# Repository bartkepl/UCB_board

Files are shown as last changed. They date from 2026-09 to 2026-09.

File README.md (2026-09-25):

# UCB (Universal Control Board)
Control board for testing concepts with SCPI, UART, USB, RS485 and ETHERNET in 3U eurocard format

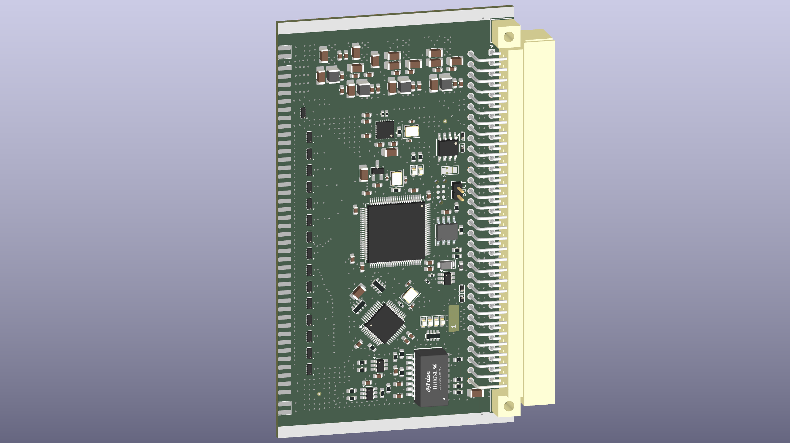
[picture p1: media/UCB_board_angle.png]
Universal Control board


| Top | Bottom |
|---|---|
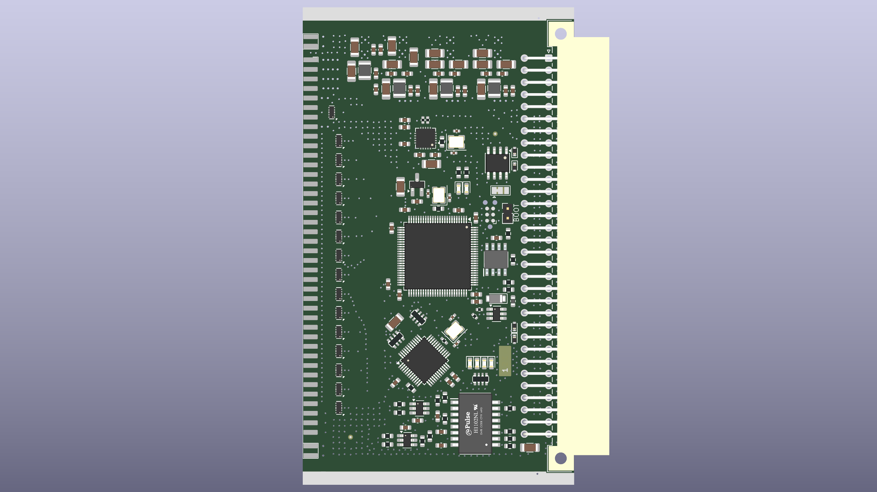
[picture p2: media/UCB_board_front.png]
Top
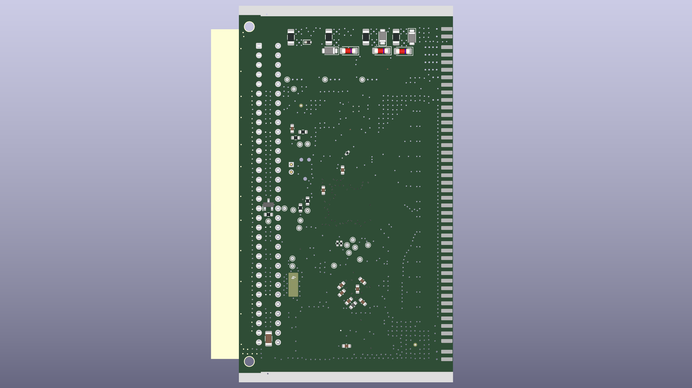
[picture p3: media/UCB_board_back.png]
Bottom
|  |  |

---
## Status: ready for prototype order

- Schematic and PCB layout done (4-layer, 56.8 × 100 mm), production files generated.
- Design review completed; DRC/ERC clean (remaining items reviewed and excluded as by-design).
- W5500 clock is sourced from the MCU (MCO1) by default — R80 fitted, R23 (Si5351C CLK0) DNP.
- Firmware: STM32CubeMX skeleton only.

Production outputs: [schematic PDF](prod/sch/UCB_board.pdf) · [PCB PDF](prod/pcb/UCB_board.pdf) · [interactive BOM](prod/ibom/UCB_board_ibom.html) · [gerbers](prod/UCB_board.zip)

---
## Features:
- ARM Cortex-M33 Processor in LQFP100 (STM32H563VIT6) 
- USB 2.0
- 10/100 Ethernet (based on WIZnet W5500)
- UART
- Half-duplex RS485 
- 3U eurocard IEEE 1101.1-1998 format (160x100 mm) — this 56.8 × 100 mm backend board is combined with a 100 × 100 mm front module (e.g. SSM_board)
----

## License and Contribution

[MIT License](/LICENSE)

Open to contributions in both software and hardware!

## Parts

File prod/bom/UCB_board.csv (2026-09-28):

Oznaczenie | Wartość | Footprint | Opis | Liczba
C1,C2,C11,C12,C13,C14,C15,C16,C17,C23,C24,C26,C28,C29,C32,C33,C35,C37,C38,C39,C41,C42,C45,C46,C49,C50,C52,C53,C54,C55,C58,C68,C69,C70,C71 | 100n | Capacitor_SMD:C_0603_1608Metric | Unpolarized capacitor | 35
C3,C5 | 1nF/2kV | Capacitor_SMD:C_1206_3216Metric | Unpolarized capacitor | 2
C4,C7,C10,C27 | 10n | Capacitor_SMD:C_0603_1608Metric | Unpolarized capacitor | 4
C6,C8 | 18p | Capacitor_SMD:C_0402_1005Metric_Pad0.74x0.62mm_HandSolder | Unpolarized capacitor | 2
C9,C56,C57 | 4.7u | Capacitor_SMD:C_0603_1608Metric | Unpolarized capacitor | 3
C18,C21,C22,C30,C31,C34,C36,C43,C47,C48,C51,C67 | 10u | Capacitor_SMD:C_1206_3216Metric | Unpolarized capacitor | 12
C73,C74 | 6.8n | Capacitor_SMD:C_0603_1608Metric | Unpolarized capacitor | 2
D1,D2,D4,D6,D13,D14 | Green | LED_SMD:LED_0603_1608Metric | Light emitting diode | 6
D3,D5,D10,D16,D17 | ESD5Z3.3T1G | Diode_SMD:D_SOD-523 | ESD Protection Diode, SOD-523 | 5
D7,D12 | SMF5.0CA | Diode_SMD:D_SMF | SMF5.0CA | 2
D8,D18 | TGL34-15CA | Diode_SMD:D_MiniMELF | TGL34-15CA | 2
D9,D19 | BZD27C12P-E3-08 | Diode_SMD:D_SMF |  | 2
D11 | TGL34-6.8CA | Diode_SMD:D_MiniMELF | TGL34-6.8CA | 1
D15 | CDSOT23-SM712 | SamacSys_Parts:SOT95P230X117-3N | TVS Diode Dual Bi-Dir 7/12V 30KV SOT23 Bourns CDSOT23-SM712 Dual Bi-Directional TVS Diode, 400W peak, 3-Pin SOT-23 | 1
D20,D21,D22,D23,D24,D25,D26,D27,D28,D29,D30,D31,D32,D33,D34,D35 | UT8413A | Package_DFN_QFN:Diodes_UDFN-10_1.0x2.5mm_P0.5mm | TRANSIENT VOLTAGE SUPPRESSOR (TVS) ARRAY | 16
F1,F2,F3,F4 | Polyfuse | Fuse:Fuse_1206_3216Metric_Pad1.42x1.75mm_HandSolder | Resettable fuse, polymeric positive temperature coefficient | 4
FB1,FB2 | 100 @ 100MHz | Inductor_SMD:L_0603_1608Metric | Inductor | 2
IC1 | SN65HVD75DR | SamacSys_Parts:SOIC127P600X175-8N | 3.3-V half-duplex RS-485 transceiver with IEC ESD, 20 Mbps | 1
L1,L2,L3,L4 | LQH32PN101MN0L | Inductor_SMD:L_1210_3225Metric | Inductor | 4
R1,R2 | 22 | Resistor_SMD:R_0402_1005Metric | Resistor | 2
R3,R21,R84,R85,R90,R91 | 10k | Resistor_SMD:R_0603_1608Metric | Resistor | 6
R4 | 15k | Resistor_SMD:R_0603_1608Metric | Resistor | 1
R5,R88,R89 | 10 | Resistor_SMD:R_0603_1608Metric | Pulse-Proof Thick-Film Resistor,Resistor | 3
R6,R7 | 75 | Resistor_SMD:R_0603_1608Metric | Resistor | 2
R8,R9 | 82 | Resistor_SMD:R_0603_1608Metric | Resistor | 2
R10,R11 | 49.9 | Resistor_SMD:R_0603_1608Metric | Resistor | 2
R12,R13 | 150 | Resistor_SMD:R_0603_1608Metric | Resistor | 2
R14,R15,R16,R17 | 33 | Resistor_SMD:R_0603_1608Metric | Resistor | 4
R18,R20 | 1M | Resistor_SMD:R_0402_1005Metric_Pad0.72x0.64mm_HandSolder,Resistor_SMD:R_0603_1608Metric | Resistor | 2
R19 | 12.4k | Resistor_SMD:R_0603_1608Metric | Resistor | 1
R80 | 0R | Resistor_SMD:R_0402_1005Metric | Resistor | 1
R86,R87 | 120 | Resistor_SMD:R_0603_1608Metric | Resistor | 2
RN1 | 4x470R | Resistor_SMD:R_Array_Convex_4x0603 | Resistor array | 1
RN2,RN3 | 4x10k | Resistor_SMD:R_Array_Convex_4x0603 | Resistor array | 2
T1 | H1102NL | SamacSys_Parts:SOIC127P940X597-16N | PULSE ELECTRONICS - H1102NL - TRANSFORMER, 1:1, 1PORT, 100BASE-TX, SMT | 1
U1 | W5500 | Package_QFP:LQFP-48_7x7mm_P0.5mm | 10/100Mb SPI Ethernet controller with TCP/IP stack, LQFP-48 | 1
U2 | LM4040DBZ-3 | Package_TO_SOT_SMD:SOT-23_Handsoldering | 3.000V Precision Micropower Shunt Voltage Reference, SOT-23 | 1
U3,U4,U5 | USBLC6-2SC6 | Package_TO_SOT_SMD:SOT-23-6_Handsoldering | Very low capacitance ESD protection diode, 2 data-line, SOT-23-6 | 3
U6 | FM24C64B | Package_SO:SOIC-8_3.9x4.9mm_P1.27mm | 64Kb serial FRAM nonvolatile Memory, SOIC-8 | 1
U7 | STM32H563VIT6 | Package_QFP:LQFP-100_14x14mm_P0.5mm | STMicroelectronics Arm Cortex-M33 MCU, 2048KB flash, 640KB RAM, 250 MHz, 1.62-3.6V, 80 GPIO, LQFP100 | 1
Y2 | 3225-25M-SR | Crystal:Crystal_SMD_3225-4Pin_3.2x2.5mm | Four pin crystal, GND on pins 2 and 4 | 1

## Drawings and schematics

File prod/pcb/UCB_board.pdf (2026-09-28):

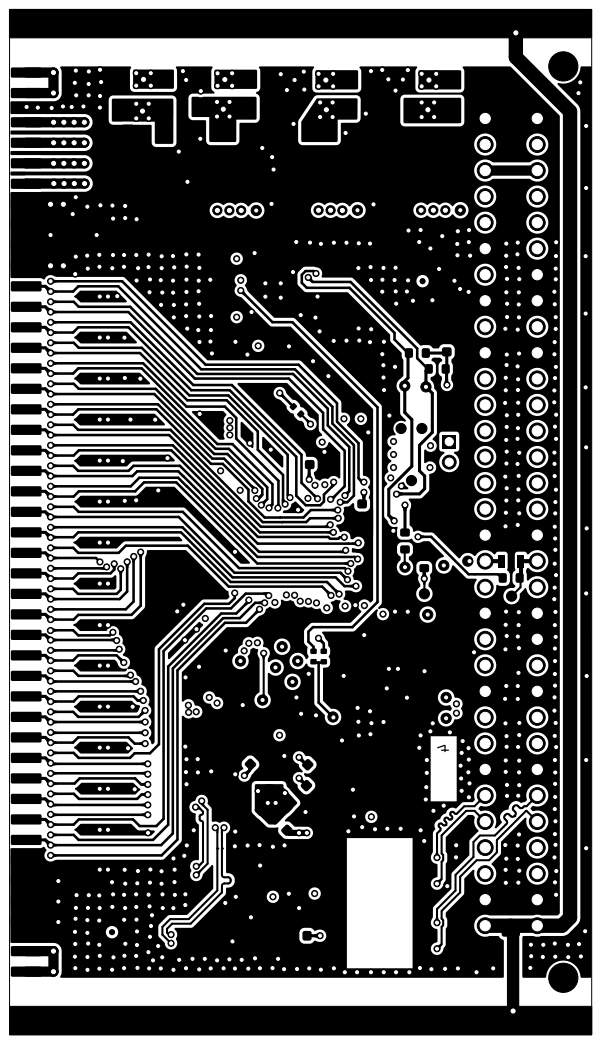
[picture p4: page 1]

Size: A4 | Rev: 0.3
KiCad E.D.A. 10.0.4 | Id: 1/6

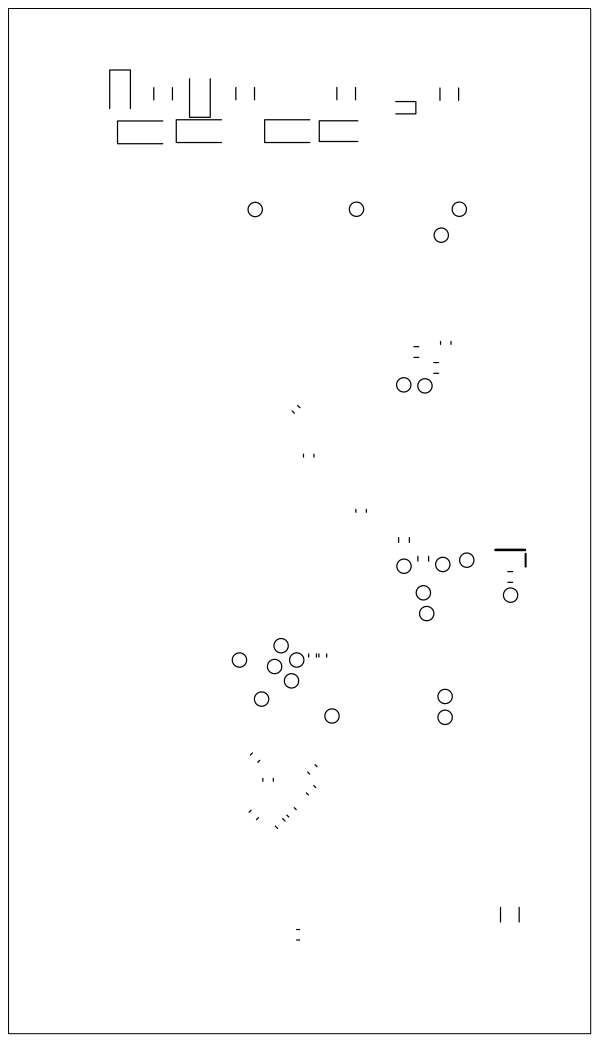
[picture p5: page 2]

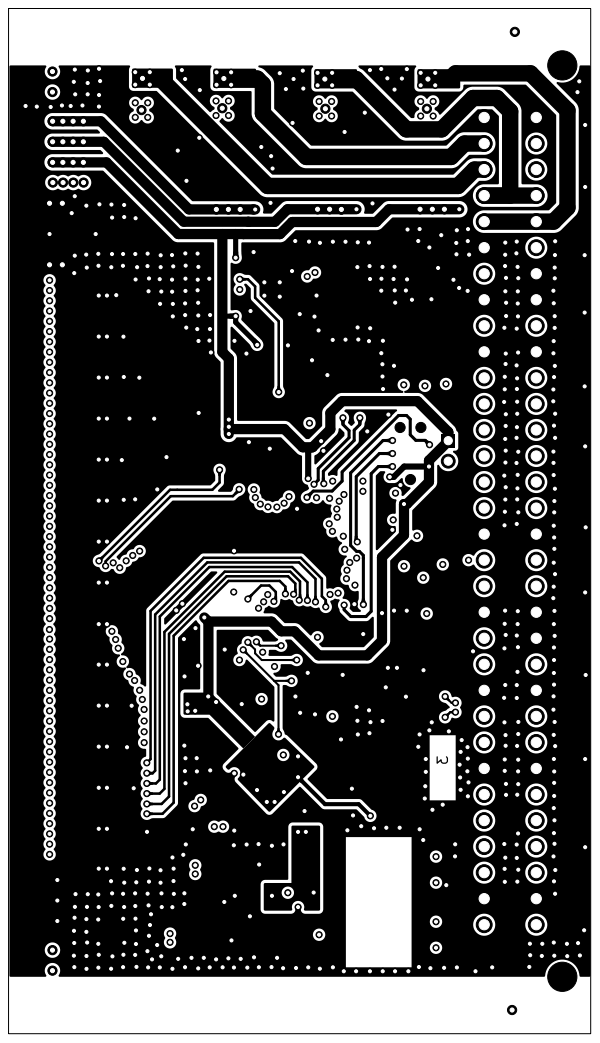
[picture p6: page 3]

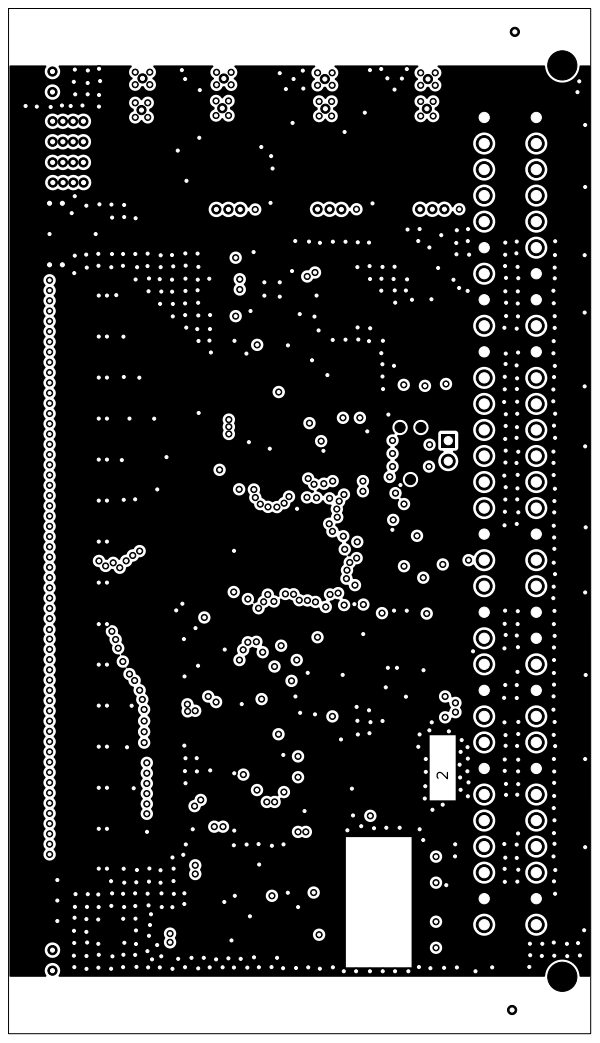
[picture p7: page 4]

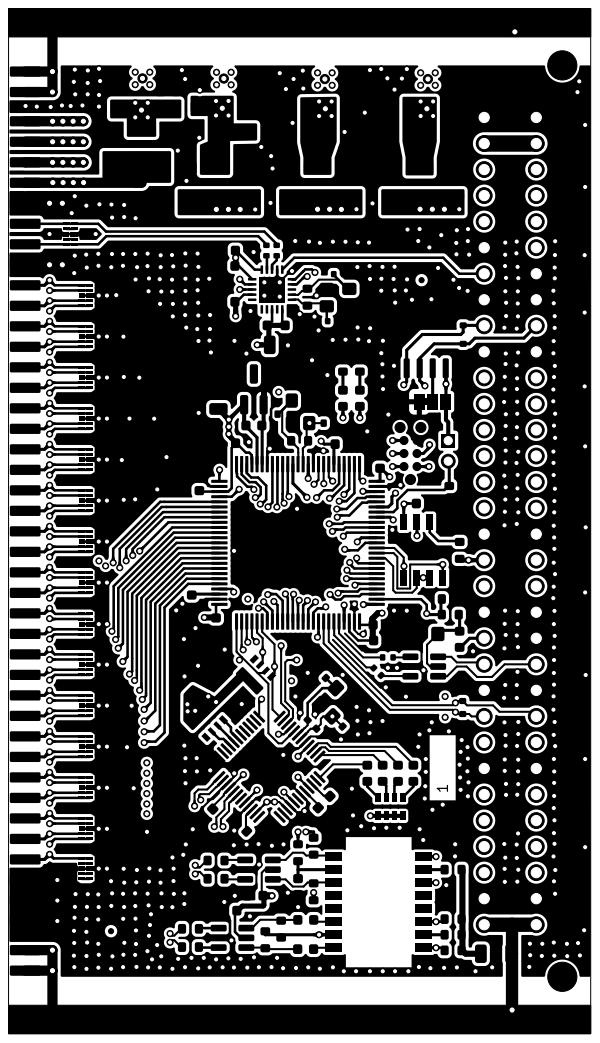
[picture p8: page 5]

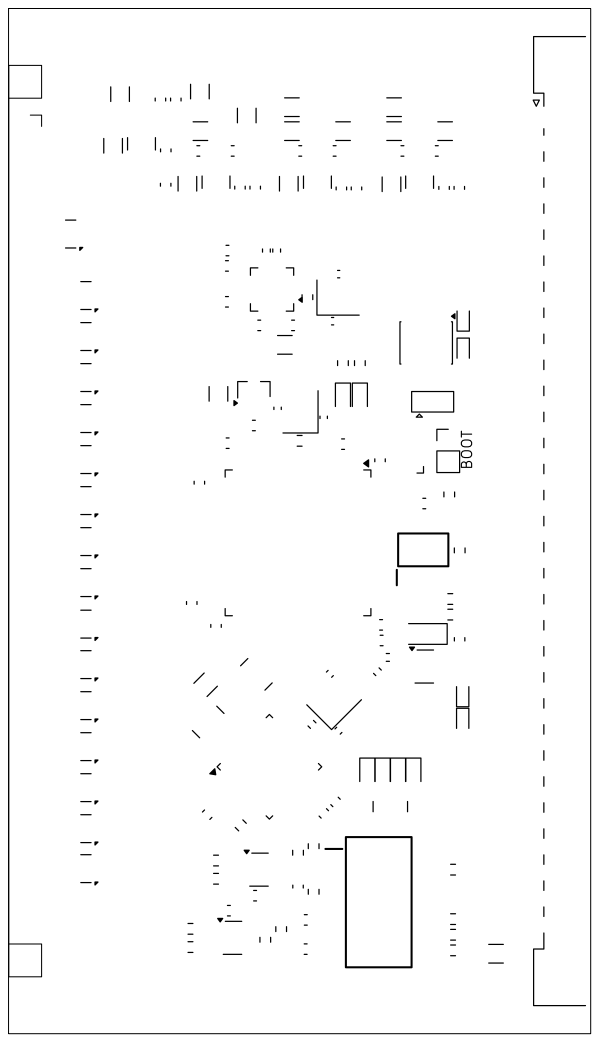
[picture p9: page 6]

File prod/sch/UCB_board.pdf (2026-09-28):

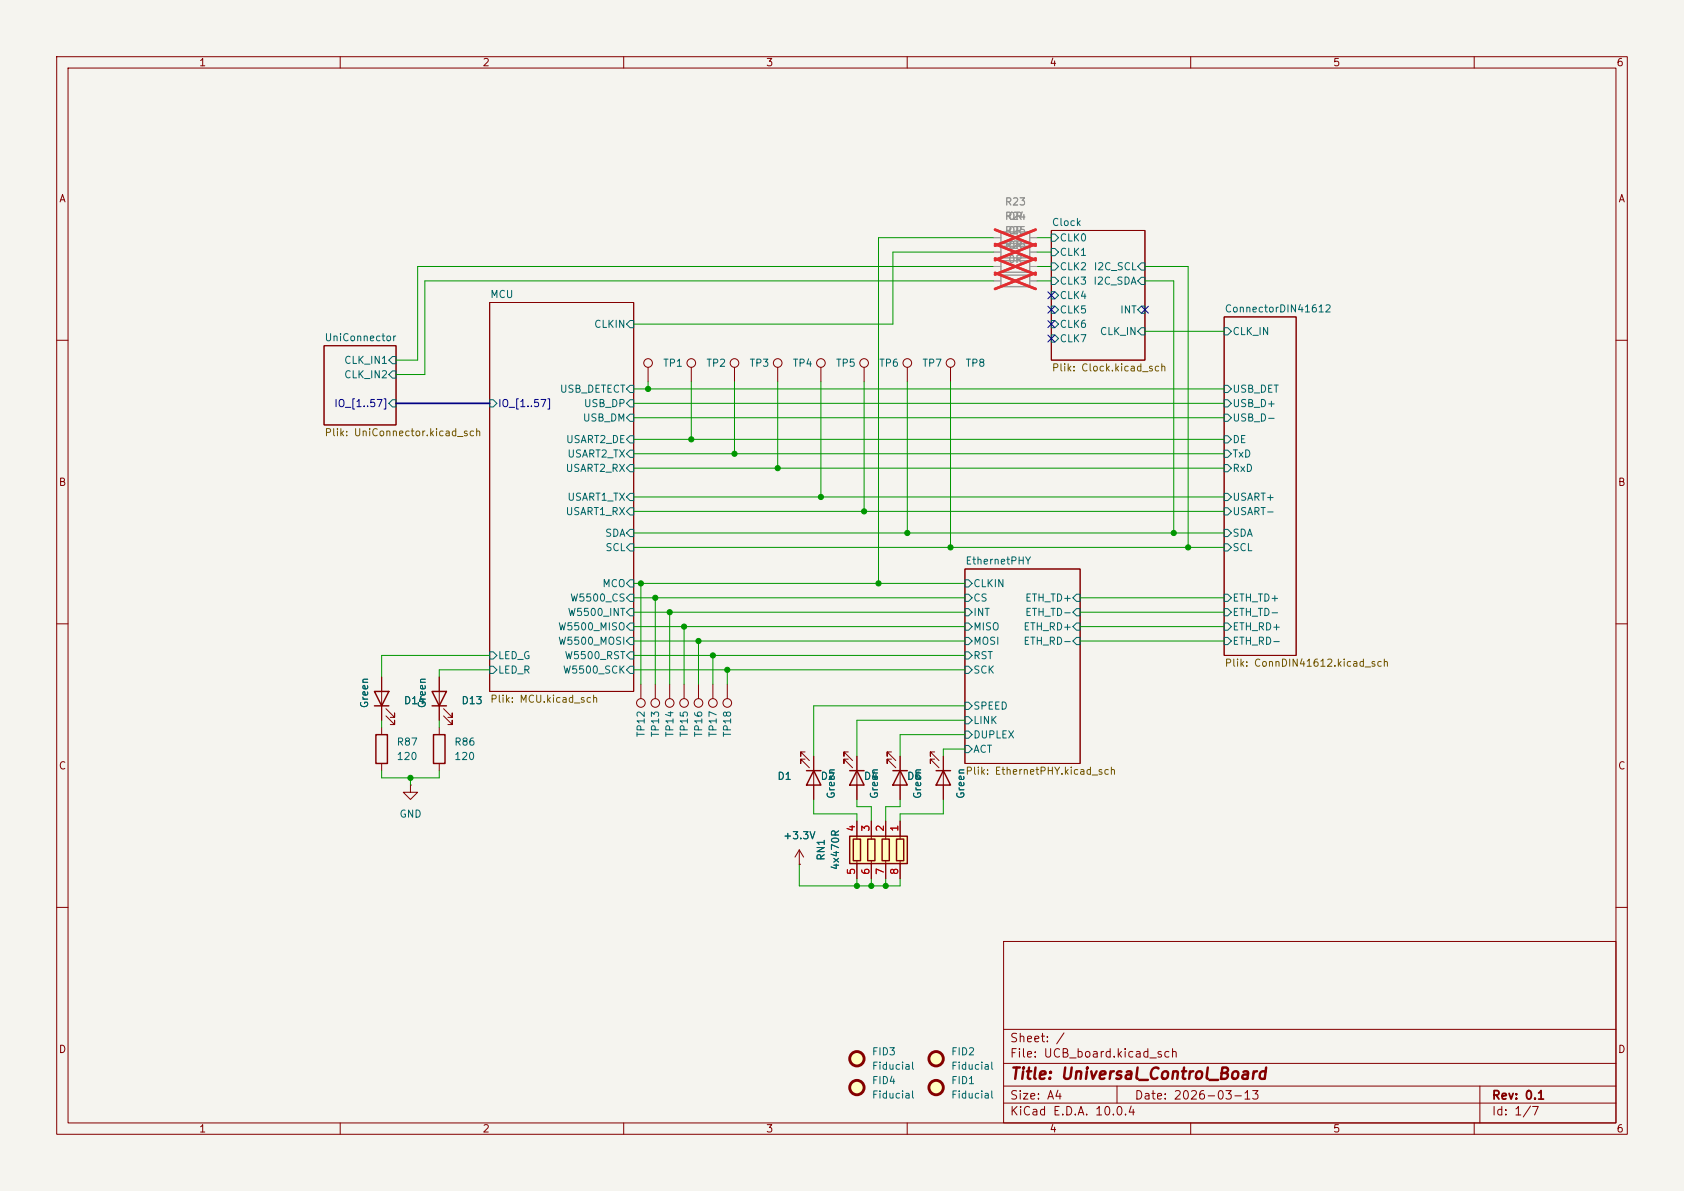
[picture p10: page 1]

INT Clock Plik: Clock.kicad_sch

EthernetPHY Plik: EthernetPHY.kicad_sch
ACT CSDUPLEX
LINK MISO MOSI RST SCK

Size: A4 | Rev: 0.1
KiCad E.D.A. 10.0.4 | Id: 1/7

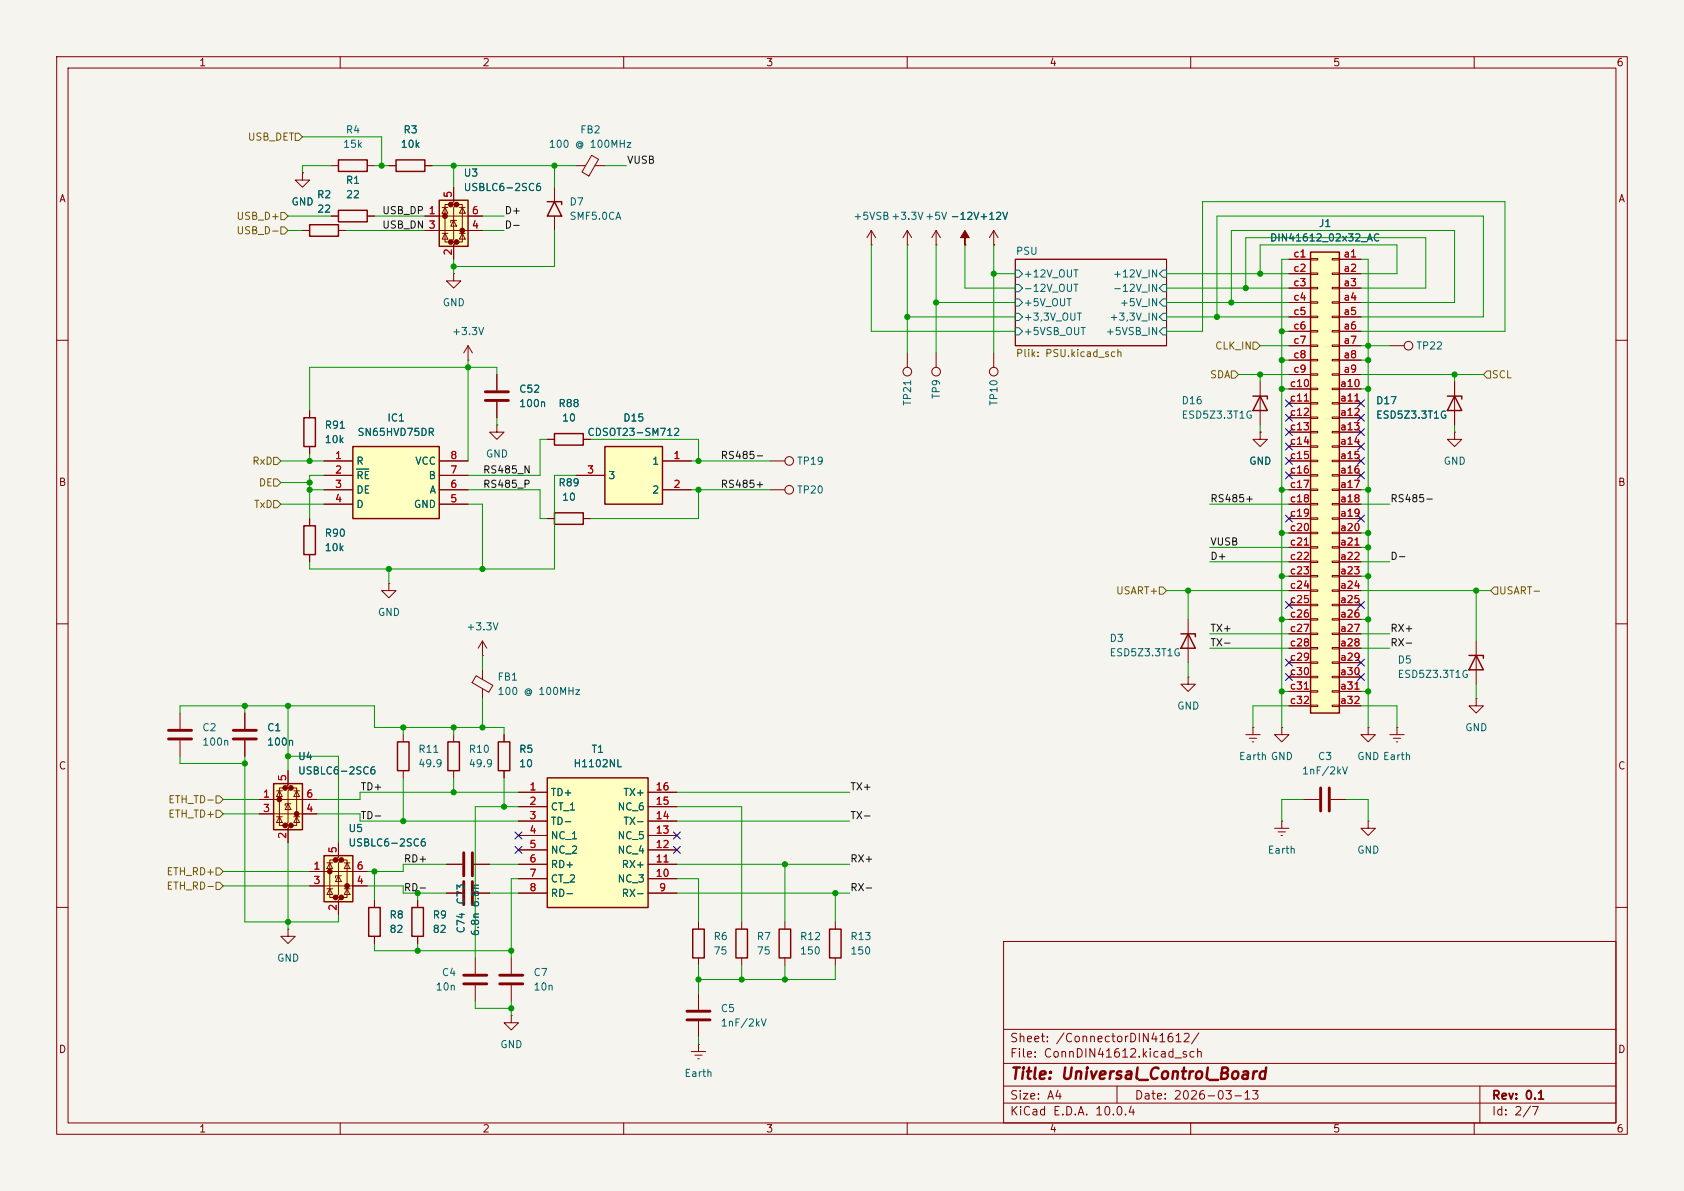
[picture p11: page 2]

c3 c3 | a3 a3
c4 c4 | a4 a4
c5 c5 | a5 a5
c6 c6 c7 c7 | a6 a6

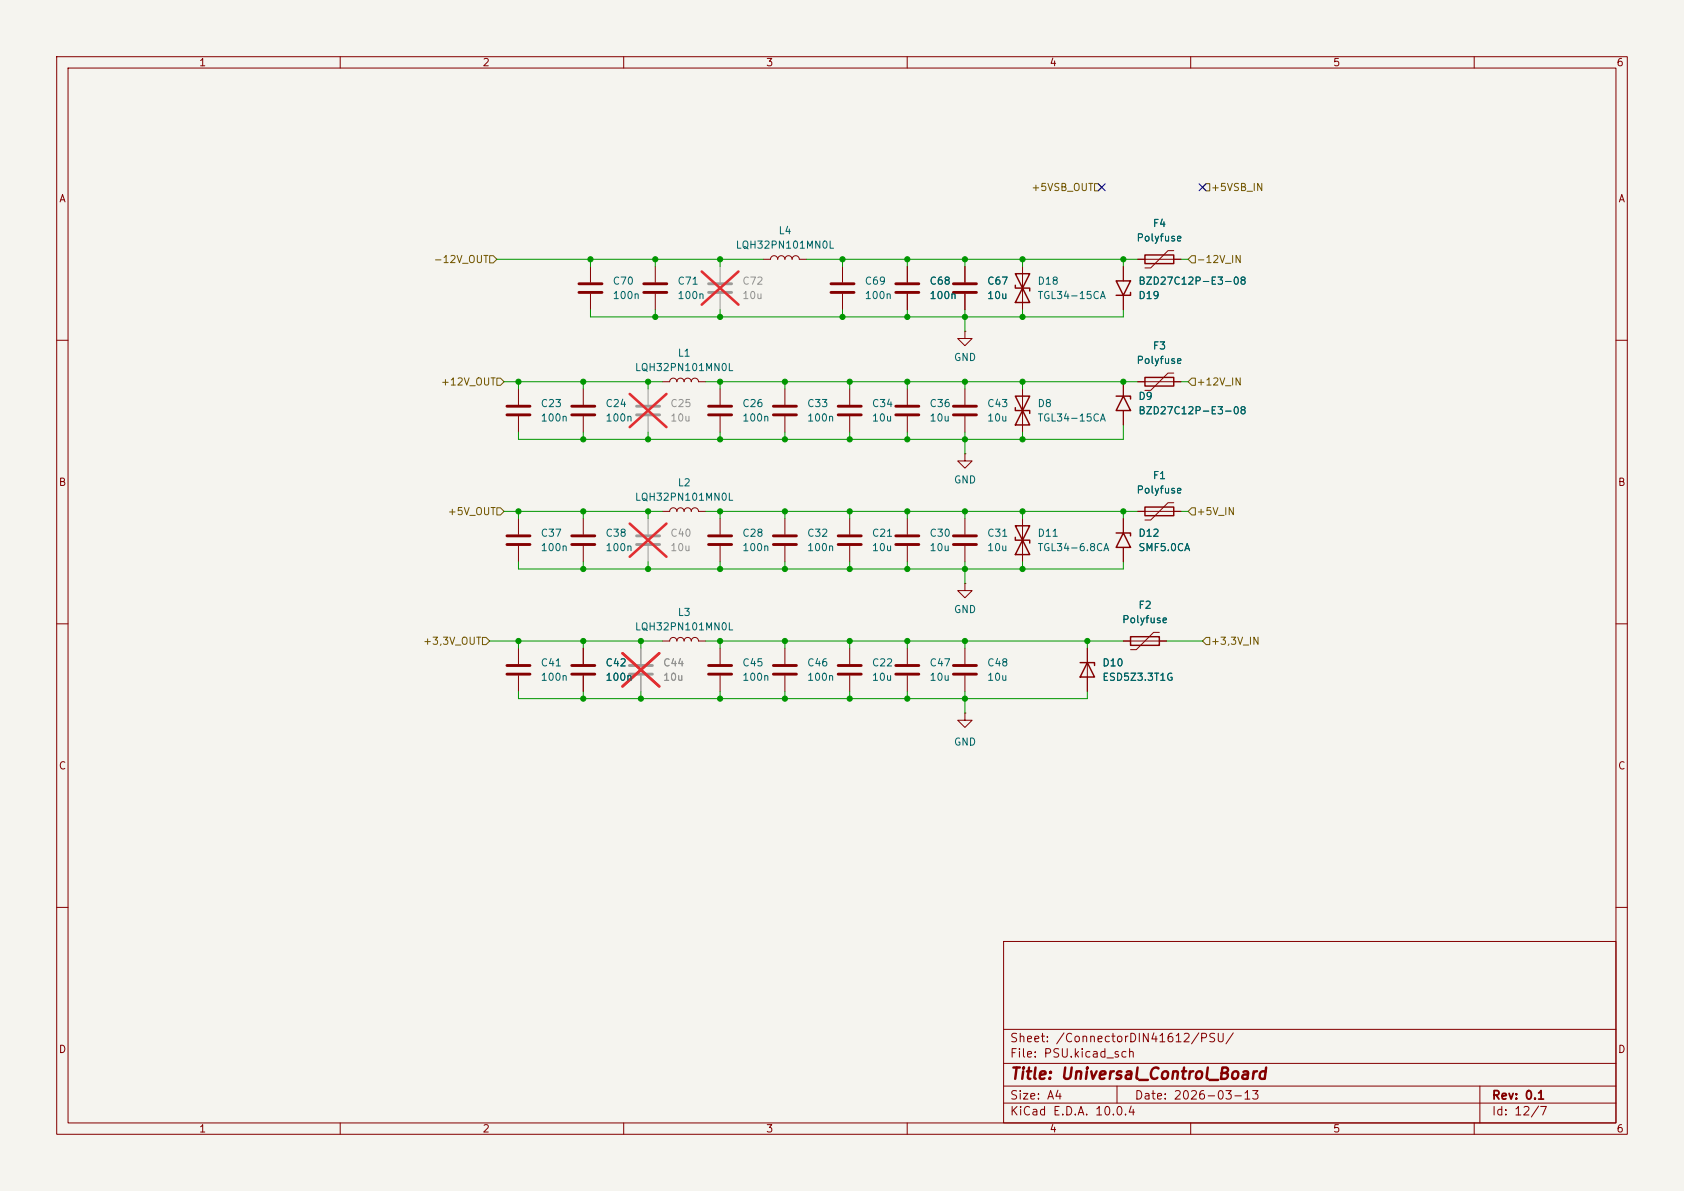
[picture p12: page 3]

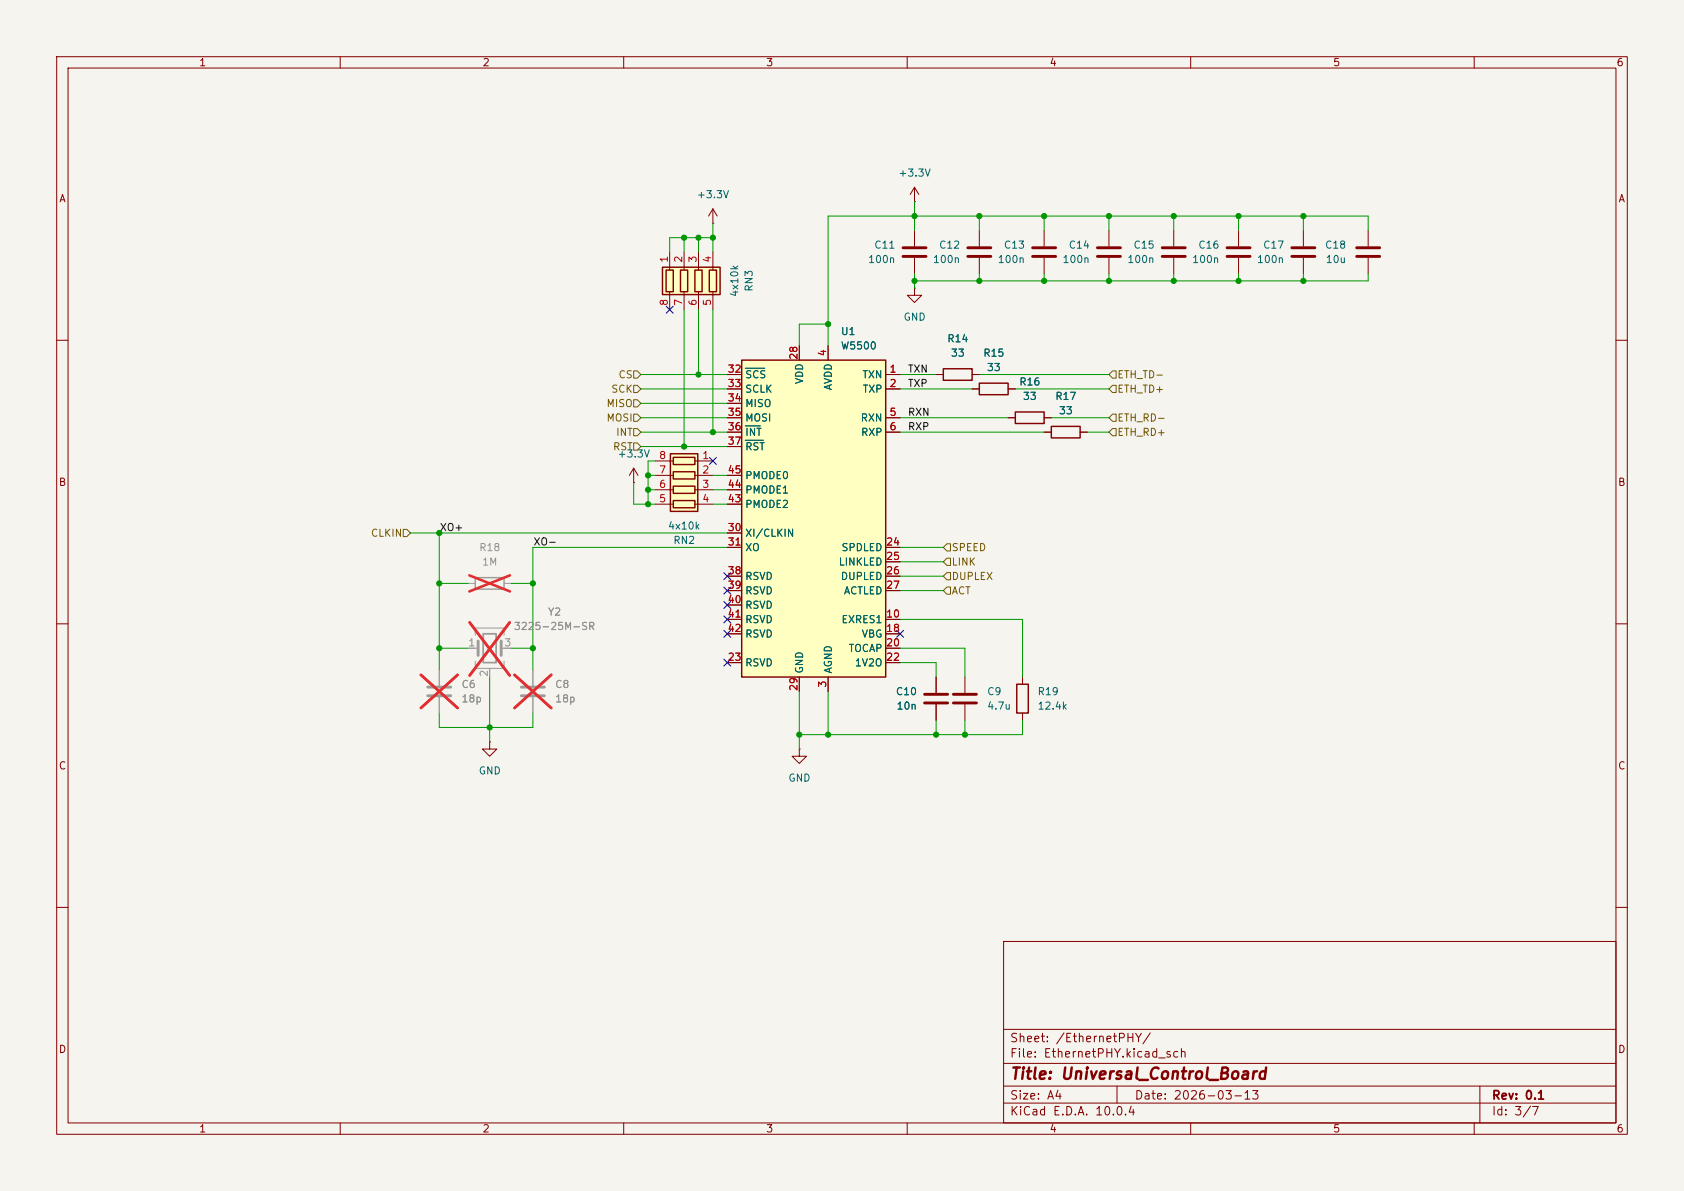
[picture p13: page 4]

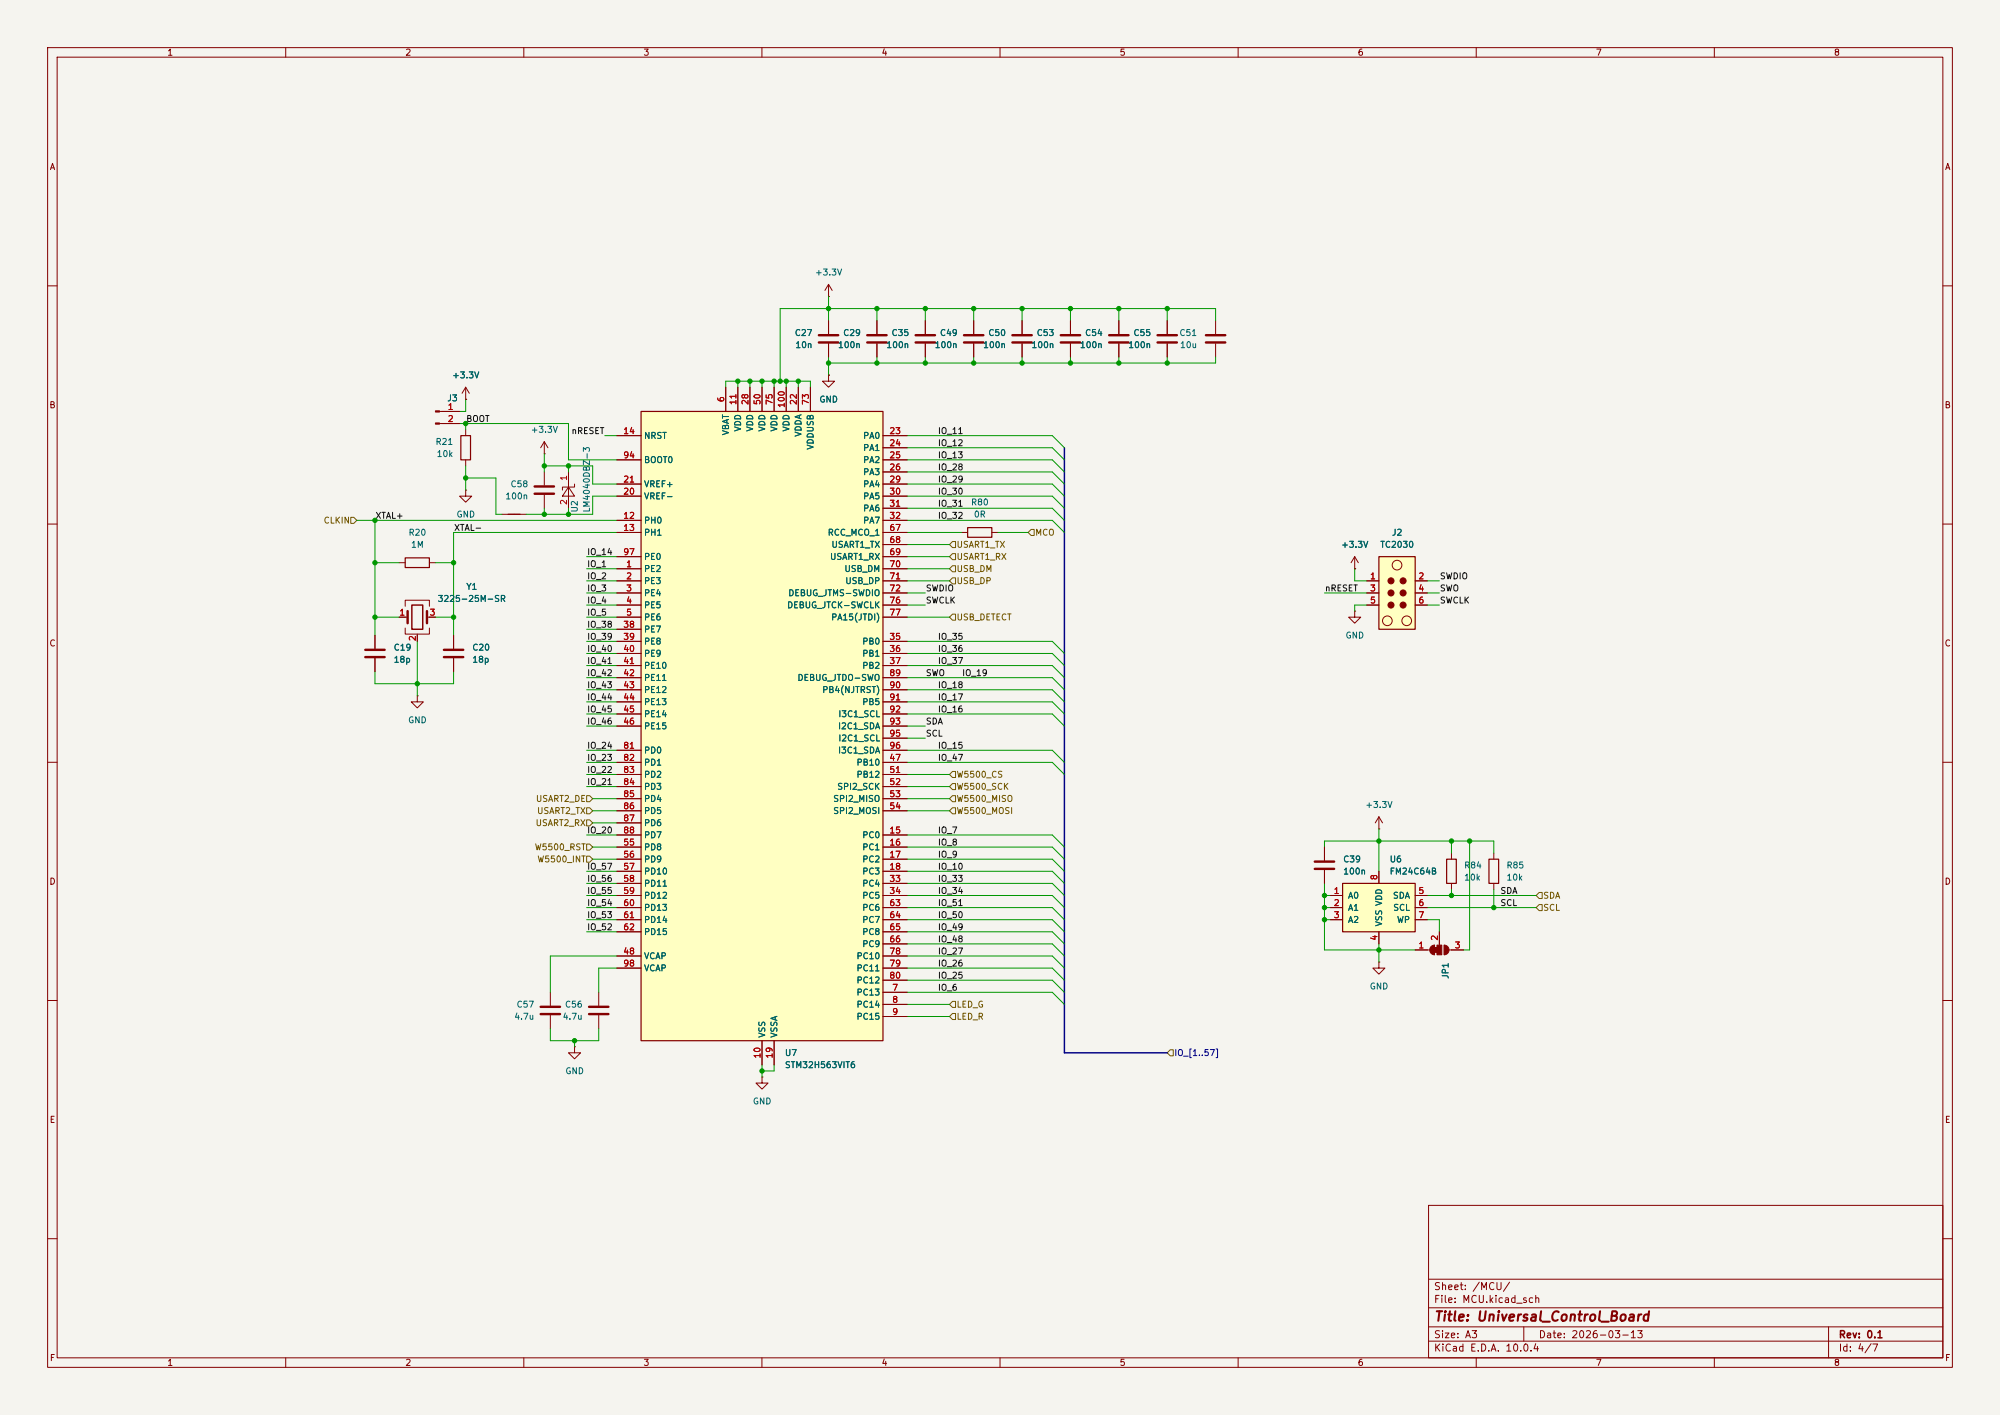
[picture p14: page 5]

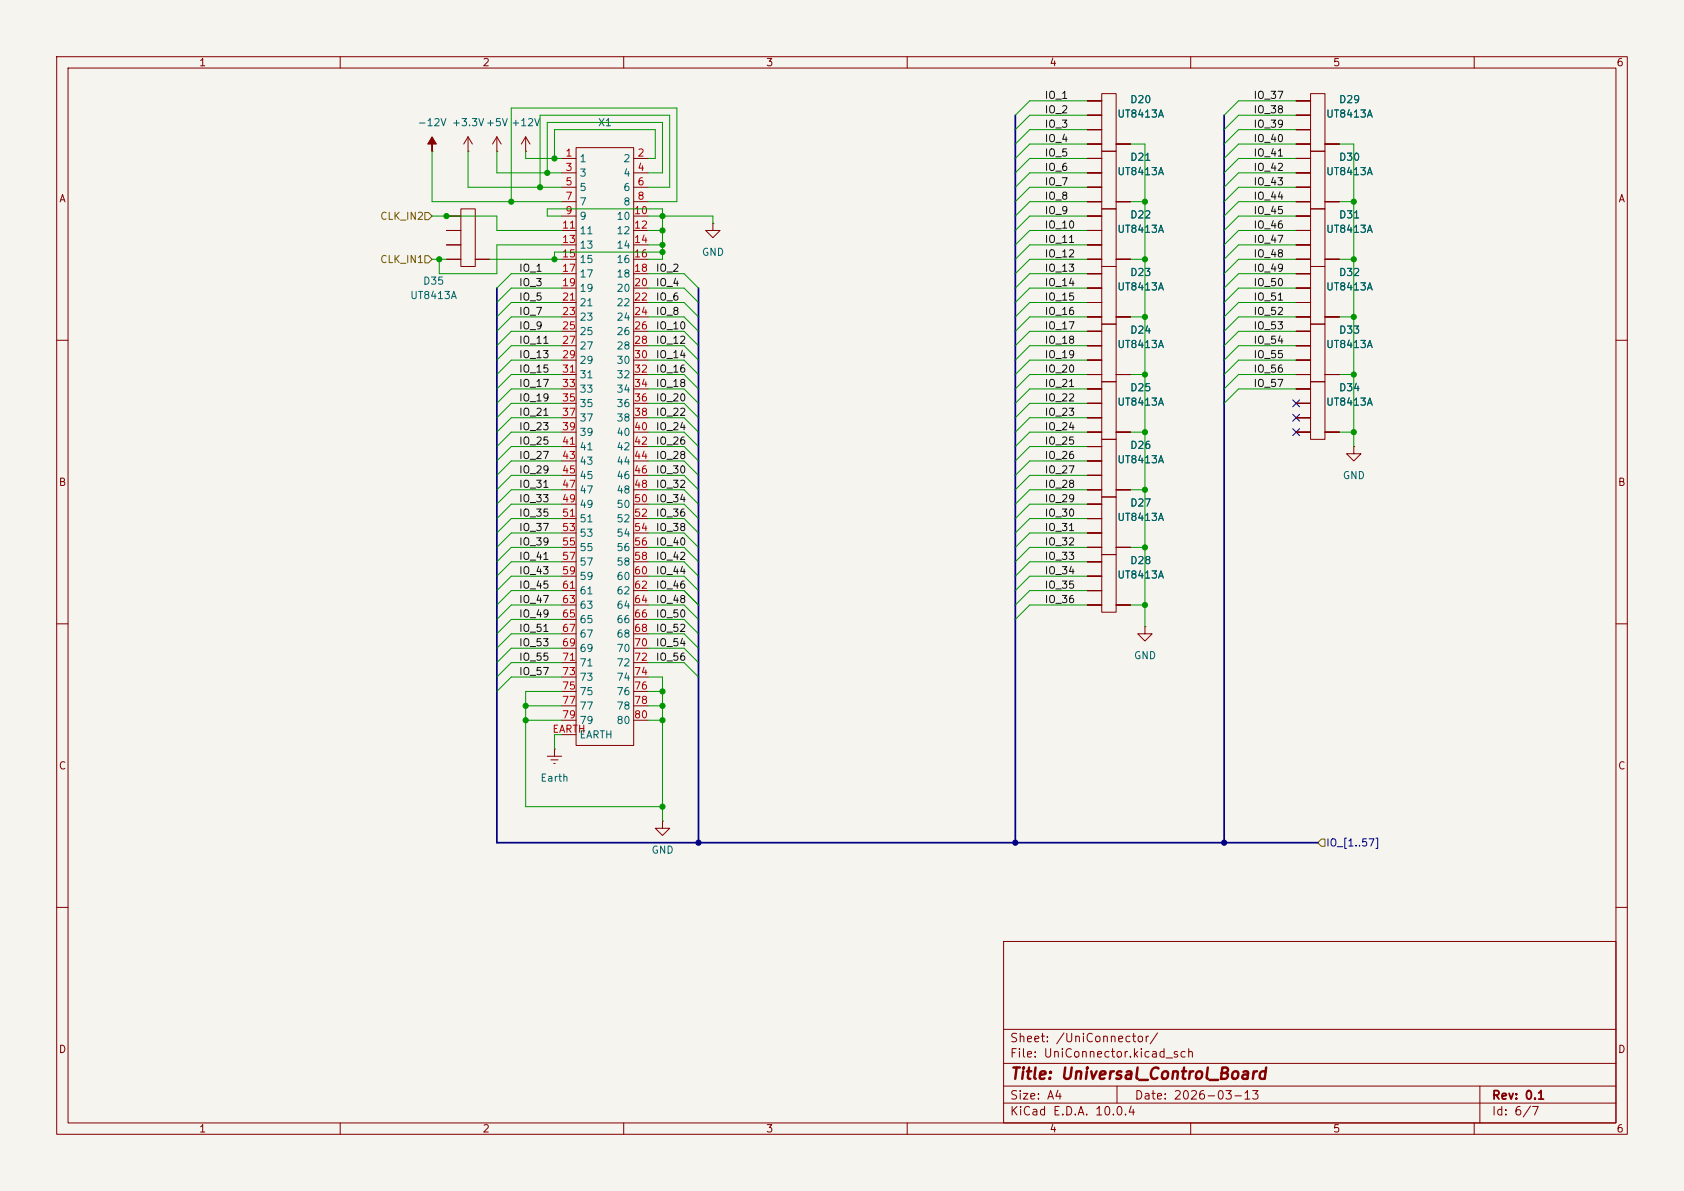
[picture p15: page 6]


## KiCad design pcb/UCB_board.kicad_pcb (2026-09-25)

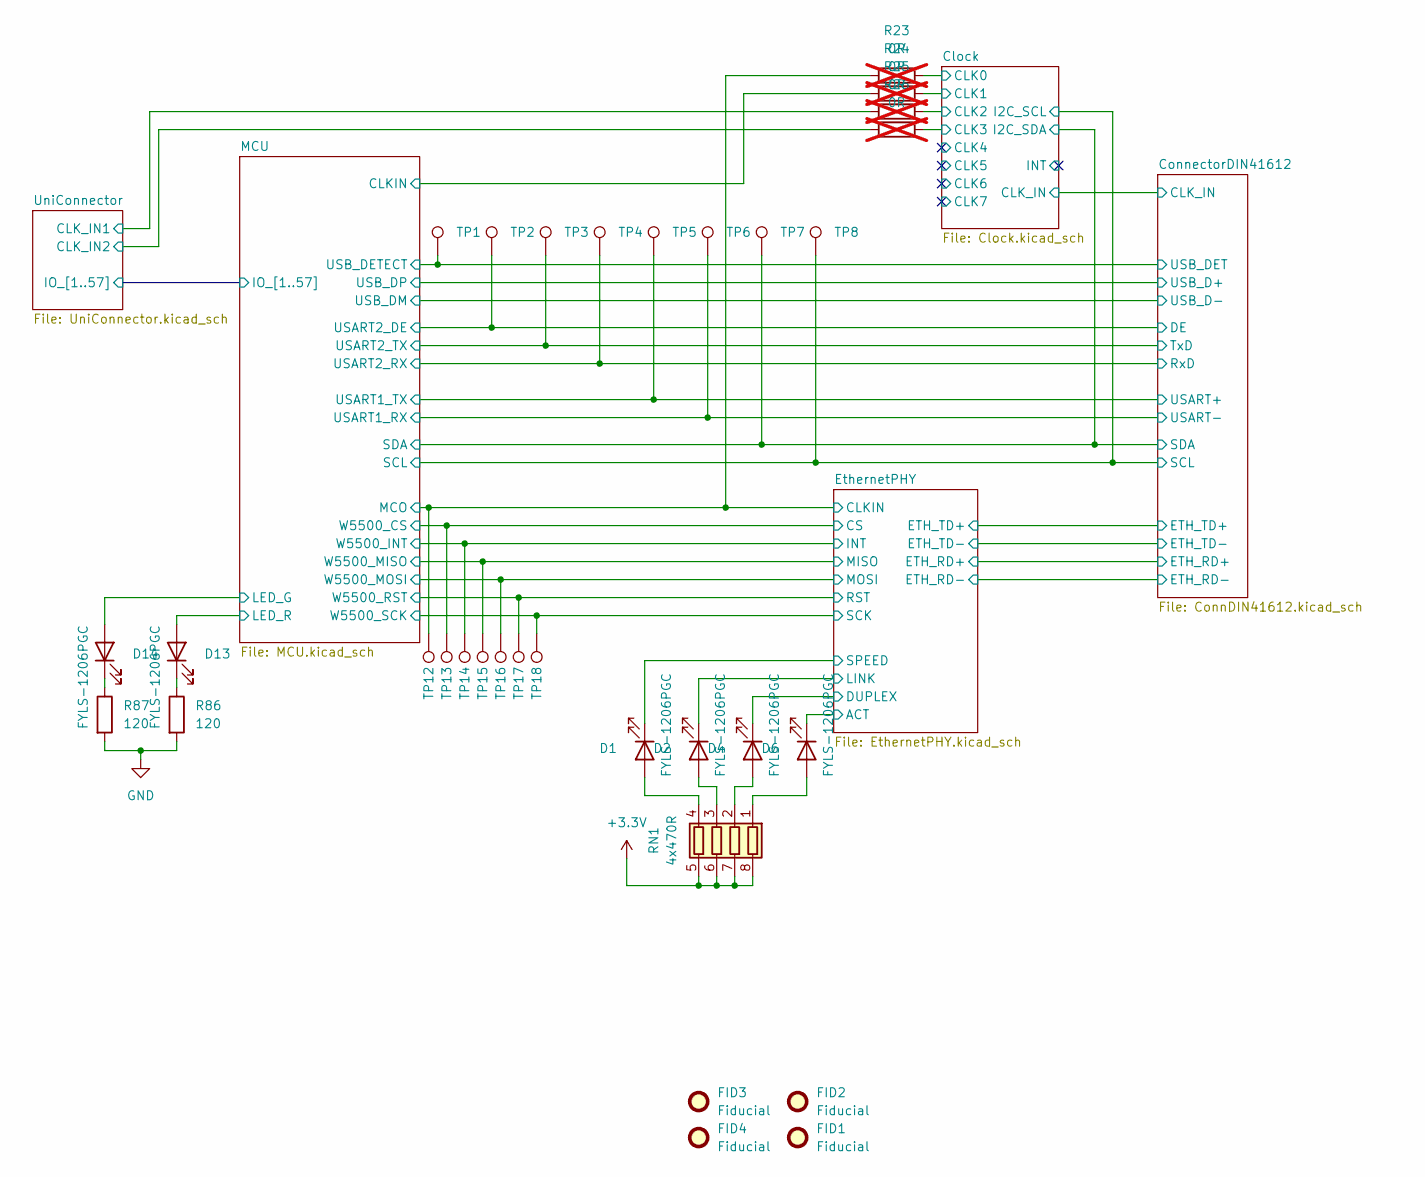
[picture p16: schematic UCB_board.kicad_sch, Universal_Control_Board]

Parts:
D1, D2, D4, D6, D13, D14: FYLS-1206PGC; LED_0603_1608Metric; Manufacturer_Part_Number FYLS-1206PGC
FID1, FID2, FID3, FID4: Fiducial; Fiducial_0.5mm_Mask1mm
R23, R24, R25, R26: 0R; R_0402_1005Metric; Manufacturer_Part_Number CRCW04020000Z0TDBC; not fitted
R86, R87: 120; R_0603_1608Metric; Manufacturer_Part_Number 0603SAF1200T5E
RN1: 4x470R; R_Array_Convex_4x0603; Manufacturer_Part_Number 4D03WGJ0471T5E
TP1, TP2, TP3, TP4, TP5, TP6, TP7, TP8, TP12, TP13, TP14, TP15, TP16, TP17, TP18: TestPoint; TestPoint_Pad_D1.0mm

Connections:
+3.3V: RN1.5 (R4.2), RN1.6 (R3.2), RN1.7 (R2.2), RN1.8 (R1.2); also elsewhere on the board
/Clock/CLK0: R23.2; also elsewhere on the board
/Clock/CLK1: R24.2; also elsewhere on the board
/Clock/CLK2: R25.2; also elsewhere on the board
/Clock/CLK3: R26.2; also elsewhere on the board
/ConnectorDIN41612/DE: TP2.1 (1_1); also elsewhere on the board
/ConnectorDIN41612/RxD: TP4.1 (1_1); also elsewhere on the board
/ConnectorDIN41612/TxD: TP3.1 (1_1); also elsewhere on the board
/ConnectorDIN41612/USART+: TP5.1 (1_1); also elsewhere on the board
/ConnectorDIN41612/USART-: TP6.1 (1_1); also elsewhere on the board
/ConnectorDIN41612/USB_DET: TP1.1 (1_1); also elsewhere on the board
/EthernetPHY/ACT: D6.1 (K); also elsewhere on the board
/EthernetPHY/CS: TP13.1 (1_1); also elsewhere on the board
/EthernetPHY/DUPLEX: D4.1 (K); also elsewhere on the board
/EthernetPHY/INT: TP14.1 (1_1); also elsewhere on the board
/EthernetPHY/LINK: D2.1 (K); also elsewhere on the board
/EthernetPHY/MISO: TP15.1 (1_1); also elsewhere on the board
/EthernetPHY/MOSI: TP16.1 (1_1); also elsewhere on the board
/EthernetPHY/RST: TP17.1 (1_1); also elsewhere on the board
/EthernetPHY/SCK: TP18.1 (1_1); also elsewhere on the board
/EthernetPHY/SPEED: D1.1 (K); also elsewhere on the board
/EthernetPHY/XO+: R23.1, TP12.1 (1_1); also elsewhere on the board
/MCU/LED_G: D14.2 (A); also elsewhere on the board
/MCU/LED_R: D13.2 (A); also elsewhere on the board
/MCU/SCL: TP8.1 (1_1); also elsewhere on the board
/MCU/SDA: TP7.1 (1_1); also elsewhere on the board
/MCU/XTAL+: R24.1; also elsewhere on the board
/UniConnector/CLK_IN1: R25.1; also elsewhere on the board
/UniConnector/CLK_IN2: R26.1; also elsewhere on the board
GND: R86.2, R87.2; also elsewhere on the board
unnamed: D1.2 (A), RN1.4 (R4.1)
unnamed: D2.2 (A), RN1.3 (R3.1)
unnamed: D4.2 (A), RN1.2 (R2.1)
unnamed: D6.2 (A), RN1.1 (R1.1)
unnamed: D13.1 (K), R86.1
unnamed: D14.1 (K), R87.1

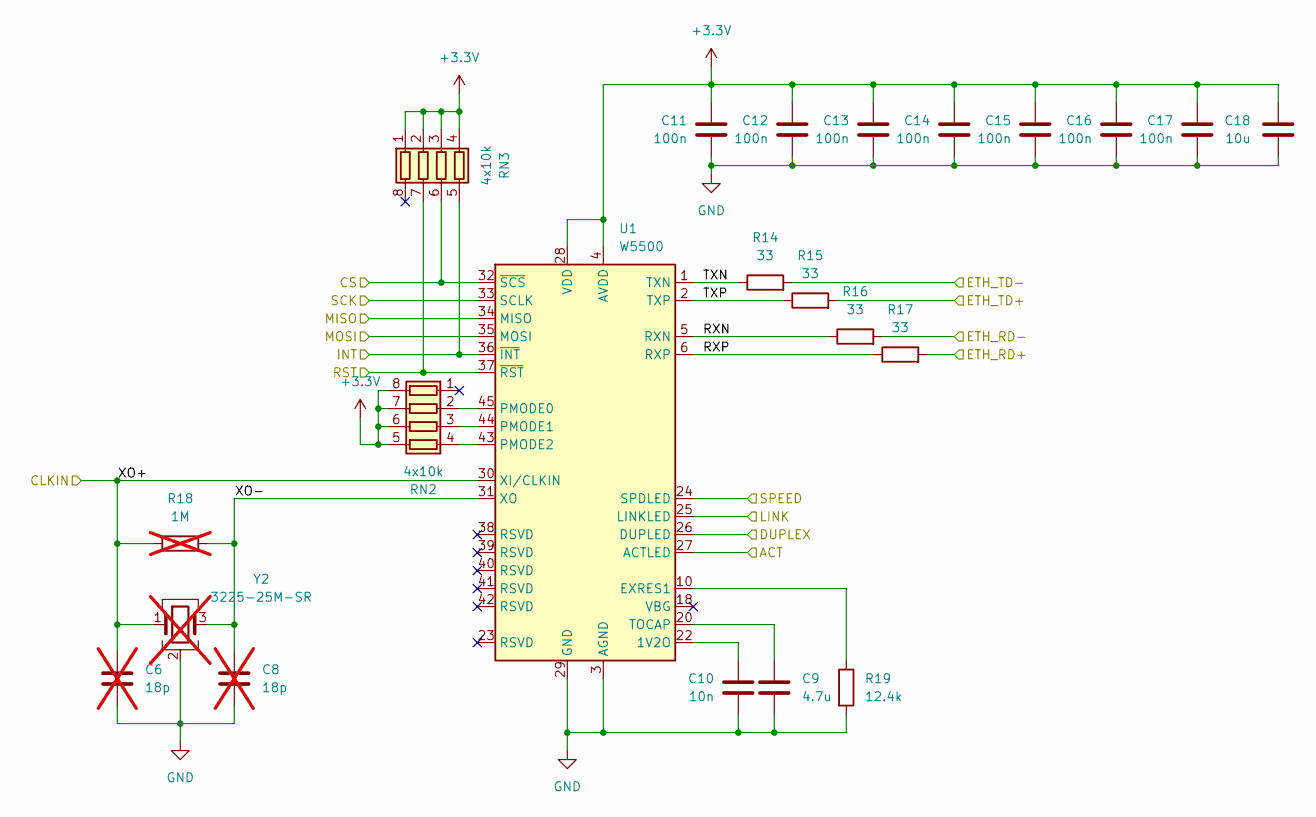
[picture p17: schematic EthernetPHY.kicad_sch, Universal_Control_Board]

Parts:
C6, C8: 18p; C_0402_1005Metric_Pad0.74x0.62mm_HandSolder; not fitted
C9: 4.7u; C_0603_1608Metric; Manufacturer_Part_Number 0603X475K100CT
C10: 10n; C_0603_1608Metric; Manufacturer_Part_Number GRM1885C1H103JA01J
C11, C12, C13, C14, C15, C16, C17: 100n; C_0603_1608Metric; Manufacturer_Part_Number GRM188R71H104KA93D
C18: 10u; C_1206_3216Metric; Manufacturer_Part_Number CL31B106KBHNNNE
R14, R15, R16, R17: 33; R_0603_1608Metric; Manufacturer_Part_Number WF06P330JTL
R18: 1M; R_0402_1005Metric_Pad0.72x0.64mm_HandSolder; not fitted
R19: 12.4k; R_0603_1608Metric; Manufacturer_Part_Number ERA3AEB1242V
RN2, RN3: 4x10k; R_Array_Convex_4x0603; Manufacturer_Part_Number 4D03WGJ0103T5E
U1: W5500; LQFP-48_7x7mm_P0.5mm; Manufacturer_Part_Number W5500
Y2: 3225-25M-SR; Crystal_SMD_3225-4Pin_3.2x2.5mm; not fitted

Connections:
+3.3V: C11.2, C12.2, C13.2, C14.2, C15.2, C16.2, C17.2, C18.1, RN2.5 (R4.2), RN2.6 (R3.2), RN2.7 (R2.2), RN2.8 (R1.2), RN3.1 (R1.1), RN3.2 (R2.1), RN3.3 (R3.1), RN3.4 (R4.1), U1.4 (AVDD), U1.8 (AVDD), U1.11 (AVDD), U1.15 (AVDD), U1.17 (AVDD), U1.21 (AVDD), U1.28 (VDD); also elsewhere on the board
/ConnectorDIN41612/ETH_RD+: R17.2; also elsewhere on the board
/ConnectorDIN41612/ETH_RD-: R16.2; also elsewhere on the board
/ConnectorDIN41612/ETH_TD+: R15.2; also elsewhere on the board
/ConnectorDIN41612/ETH_TD-: R14.2; also elsewhere on the board
/EthernetPHY/ACT: U1.27 (ACTLED); also elsewhere on the board
/EthernetPHY/CS: RN3.6 (R3.2), U1.32 (~SCS); also elsewhere on the board
/EthernetPHY/DUPLEX: U1.26 (DUPLED); also elsewhere on the board
/EthernetPHY/INT: RN3.5 (R4.2), U1.36 (~INT); also elsewhere on the board
/EthernetPHY/LINK: U1.25 (LINKLED); also elsewhere on the board
/EthernetPHY/MISO: U1.34 (MISO); also elsewhere on the board
/EthernetPHY/MOSI: U1.35 (MOSI); also elsewhere on the board
/EthernetPHY/RST: RN3.7 (R2.2), U1.37 (~RST); also elsewhere on the board
/EthernetPHY/RXN: R16.1, U1.5 (RXN)
/EthernetPHY/RXP: R17.1, U1.6 (RXP)
/EthernetPHY/SCK: U1.33 (SCLK); also elsewhere on the board
/EthernetPHY/SPEED: U1.24 (SPDLED); also elsewhere on the board
/EthernetPHY/TXN: R14.1, U1.1 (TXN)
/EthernetPHY/TXP: R15.1, U1.2 (TXP)
/EthernetPHY/XO+: C6.1, R18.1, U1.30 (XI/CLKIN), Y2.1; also elsewhere on the board
/EthernetPHY/XO-: C8.1, R18.2, U1.31 (XO), Y2.3
GND: C6.2, C8.2, C9.2, C10.1, C11.1, C12.1, C13.1, C14.1, C15.1, C16.1, C17.1, C18.2, R19.2, U1.3 (AGND), U1.9 (AGND), U1.14 (AGND), U1.16 (AGND), U1.19 (AGND), U1.29 (GND), U1.48 (AGND), Y2.2 (G), Y2.4 (G); also elsewhere on the board
unnamed: RN2.2 (R2.1), U1.45 (PMODE0)
unnamed: RN2.3 (R3.1), U1.44 (PMODE1)
unnamed: RN2.4 (R4.1), U1.43 (PMODE2)
unnamed: C10.2, U1.22 (1V2O)
unnamed: R19.1, U1.10 (EXRES1)
unnamed: C9.1, U1.20 (TOCAP)

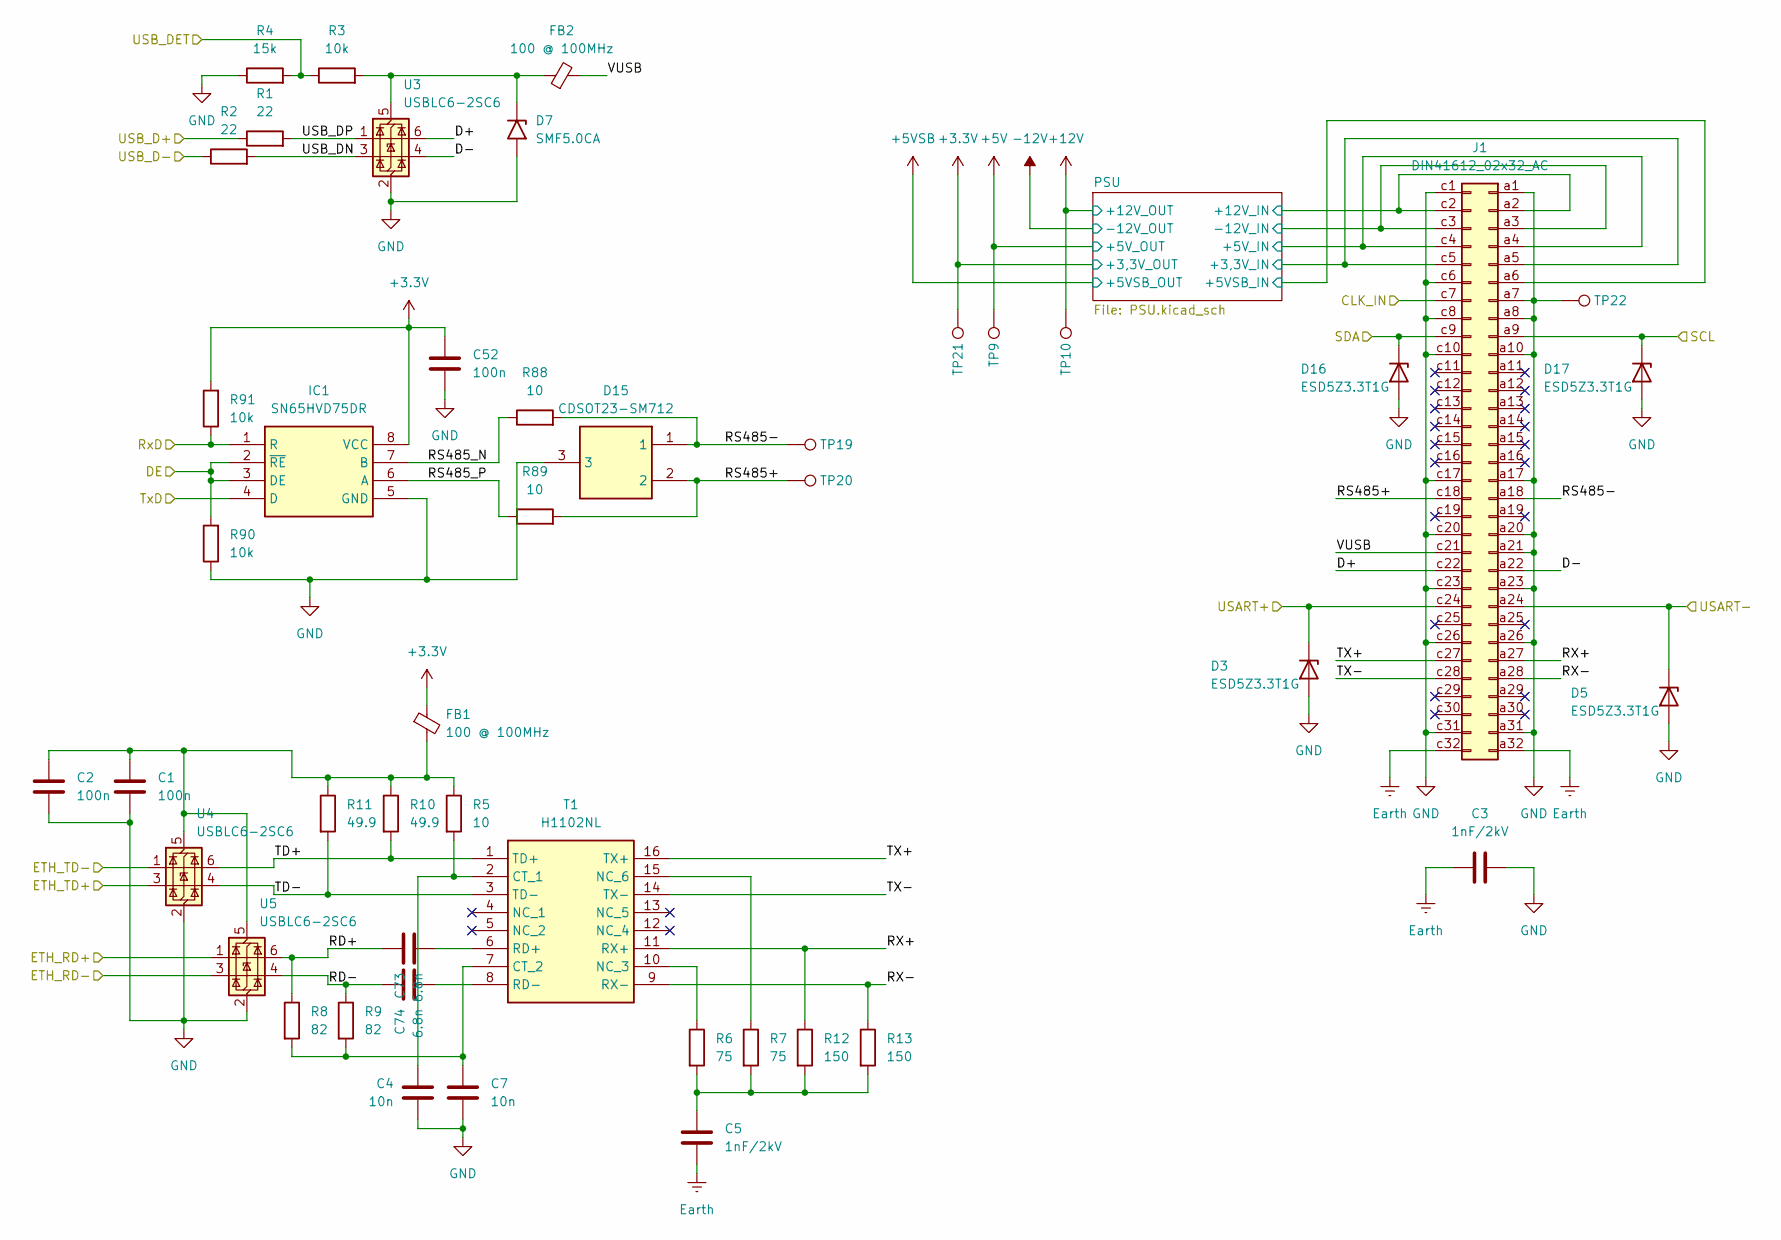
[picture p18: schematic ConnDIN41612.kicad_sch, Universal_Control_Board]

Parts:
C1, C2, C52: 100n; C_0603_1608Metric; Manufacturer_Part_Number GRM188R71H104KA93D
C3, C5: 1nF/2kV; C_1206_3216Metric; Manufacturer_Part_Number 1206B102K202
C4, C7: 10n; C_0603_1608Metric; Manufacturer_Part_Number GRM1885C1H103JA01J
C73, C74: 6.8n; C_0603_1608Metric
D3, D5, D16, D17: ESD5Z3.3T1G; D_SOD-523; Manufacturer_Part_Number ESD5Z3.3T1G
D7: SMF5.0CA; D_SMF; Manufacturer_Part_Number SMF5.0CA
D15: CDSOT23-SM712; SOT95P230X117-3N; Manufacturer_Part_Number CDSOT23-SM712
FB1, FB2: 100 @ 100MHz; L_0603_1608Metric; Manufacturer_Part_Number WLBD1608HCU101TL
IC1: SN65HVD75DR; SOIC127P600X175-8N; Manufacturer_Part_Number SN65HVD75DR
J1: DIN41612_02x32_AC; DIN41612_C_2x32_Male_Horizontal_THT
R1, R2: 22; R_0402_1005Metric; Manufacturer_Part_Number 0402WGJ0220TCE
R3, R90, R91: 10k; R_0603_1608Metric; Manufacturer_Part_Number CRCW060310K0FKTABC
R4: 15k; R_0603_1608Metric; Manufacturer_Part_Number RC0603FR-0715KL
R5, R88, R89: 10; R_0603_1608Metric
R6, R7: 75; R_0603_1608Metric; Manufacturer_Part_Number 0603SAJ0750T5E
R8, R9: 82; R_0603_1608Metric; Manufacturer_Part_Number RC0603JR-0782RL
R10, R11: 49.9; R_0603_1608Metric; Manufacturer_Part_Number CRCW060349R9FKTABC
R12, R13: 150; R_0603_1608Metric; Manufacturer_Part_Number 1-2176339-5
T1: H1102NL; SOIC127P940X597-16N; Manufacturer_Part_Number H1102NL
TP9, TP10, TP19, TP20, TP21, TP22: TestPoint; TestPoint_Pad_D1.0mm
U3, U4, U5: USBLC6-2SC6; SOT-23-6_Handsoldering; Manufacturer_Part_Number USBLC6-2SC6

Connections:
+3.3V: C52.1, FB1.1, IC1.8 (VCC), R91.2, TP21.1 (1_1); also elsewhere on the board
+5V: TP9.1 (1_1); also elsewhere on the board
+12V: TP10.1 (1_1); also elsewhere on the board
/Clock/CLK_IN: J1.c7; also elsewhere on the board
/ConnectorDIN41612/D+: J1.c22, U3.6 (I/O1)
/ConnectorDIN41612/D-: J1.a22, U3.4 (I/O2)
/ConnectorDIN41612/DE: IC1.2 (~RE), IC1.3 (DE), R90.2; also elsewhere on the board
/ConnectorDIN41612/ETH_RD+: U5.1 (I/O1); also elsewhere on the board
/ConnectorDIN41612/ETH_RD-: U5.3 (I/O2); also elsewhere on the board
/ConnectorDIN41612/ETH_TD+: U4.3 (I/O2); also elsewhere on the board
/ConnectorDIN41612/ETH_TD-: U4.1 (I/O1); also elsewhere on the board
/ConnectorDIN41612/PSU/+3,3V_IN: J1.a5, J1.c5; also elsewhere on the board
/ConnectorDIN41612/PSU/+5VSB_IN: J1.a6
/ConnectorDIN41612/PSU/+5V_IN: J1.a4, J1.c4; also elsewhere on the board
/ConnectorDIN41612/PSU/+12V_IN: J1.a2, J1.c2; also elsewhere on the board
/ConnectorDIN41612/PSU/-12V_IN: J1.a3, J1.c3; also elsewhere on the board
/ConnectorDIN41612/RD+: C73.2, R8.1, U5.6 (I/O1)
/ConnectorDIN41612/RD-: C74.2, R9.1, U5.4 (I/O2)
/ConnectorDIN41612/RS485+: D15.2, J1.c18, R89.2, TP20.1 (1_1)
/ConnectorDIN41612/RS485-: D15.1, J1.a18, R88.2, TP19.1 (1_1)
/ConnectorDIN41612/RS485_N: IC1.7 (B), R88.1
/ConnectorDIN41612/RS485_P: IC1.6 (A), R89.1
/ConnectorDIN41612/RX+: J1.a27, R12.1, T1.11 (RX+)
/ConnectorDIN41612/RX-: J1.a28, R13.1, T1.9 (RX-)
/ConnectorDIN41612/RxD: IC1.1 (R), R91.1; also elsewhere on the board
/ConnectorDIN41612/TD+: R10.2, T1.1 (TD+), U4.6 (I/O1)
/ConnectorDIN41612/TD-: R11.2, T1.3 (TD-), U4.4 (I/O2)
/ConnectorDIN41612/TX+: J1.c27, T1.16 (TX+)
/ConnectorDIN41612/TX-: J1.c28, T1.14 (TX-)
/ConnectorDIN41612/TxD: IC1.4 (D); also elsewhere on the board
/ConnectorDIN41612/USART+: D3.1 (K), J1.c24; also elsewhere on the board
/ConnectorDIN41612/USART-: D5.1 (K), J1.a24; also elsewhere on the board
/ConnectorDIN41612/USB_D+: R1.1; also elsewhere on the board
/ConnectorDIN41612/USB_D-: R2.1; also elsewhere on the board
/ConnectorDIN41612/USB_DET: R3.1, R4.2; also elsewhere on the board
/ConnectorDIN41612/USB_DN: R2.2, U3.3 (I/O2)
/ConnectorDIN41612/USB_DP: R1.2, U3.1 (I/O1)
/ConnectorDIN41612/VUSB: FB2.2, J1.c21
/MCU/SCL: D17.1 (K), J1.a9; also elsewhere on the board
/MCU/SDA: D16.1 (K), J1.c9; also elsewhere on the board
Earth: C3.1, C5.2, J1.a32, J1.c32; also elsewhere on the board
GND: C1.2, C2.2, C3.2, C4.1, C7.2, C52.2, D3.2 (A), D5.2 (A), D7.2 (A2), D15.3, D16.2 (A), D17.2 (A), IC1.5 (GND), J1.a1, J1.a7, J1.a8, J1.a10, J1.a17, J1.a20, J1.a21, J1.a23, J1.a26, J1.a31, J1.c1, J1.c6, J1.c8, J1.c10, J1.c17, J1.c20, J1.c23, J1.c26, J1.c31, R4.1, R90.1, TP22.1 (1_1), U3.2 (GND), U4.2 (GND), U5.2 (GND); also elsewhere on the board
unnamed: C5.1, R6.2, R7.2, R12.2, R13.2
unnamed: D7.1 (A1), FB2.1, R3.2, U3.5 (VBUS)
unnamed: C4.2, R5.2, T1.2 (CT_1)
unnamed: C7.1, R8.2, R9.2, T1.7 (CT_2)
unnamed: R6.1, T1.10 (NC_3)
unnamed: R7.1, T1.15 (NC_6)
unnamed: C73.1, T1.6 (RD+)
unnamed: C74.1, T1.8 (RD-)
unnamed: C1.1, C2.1, FB1.2, R5.1, R10.1, R11.1, U4.5 (VBUS), U5.5 (VBUS)

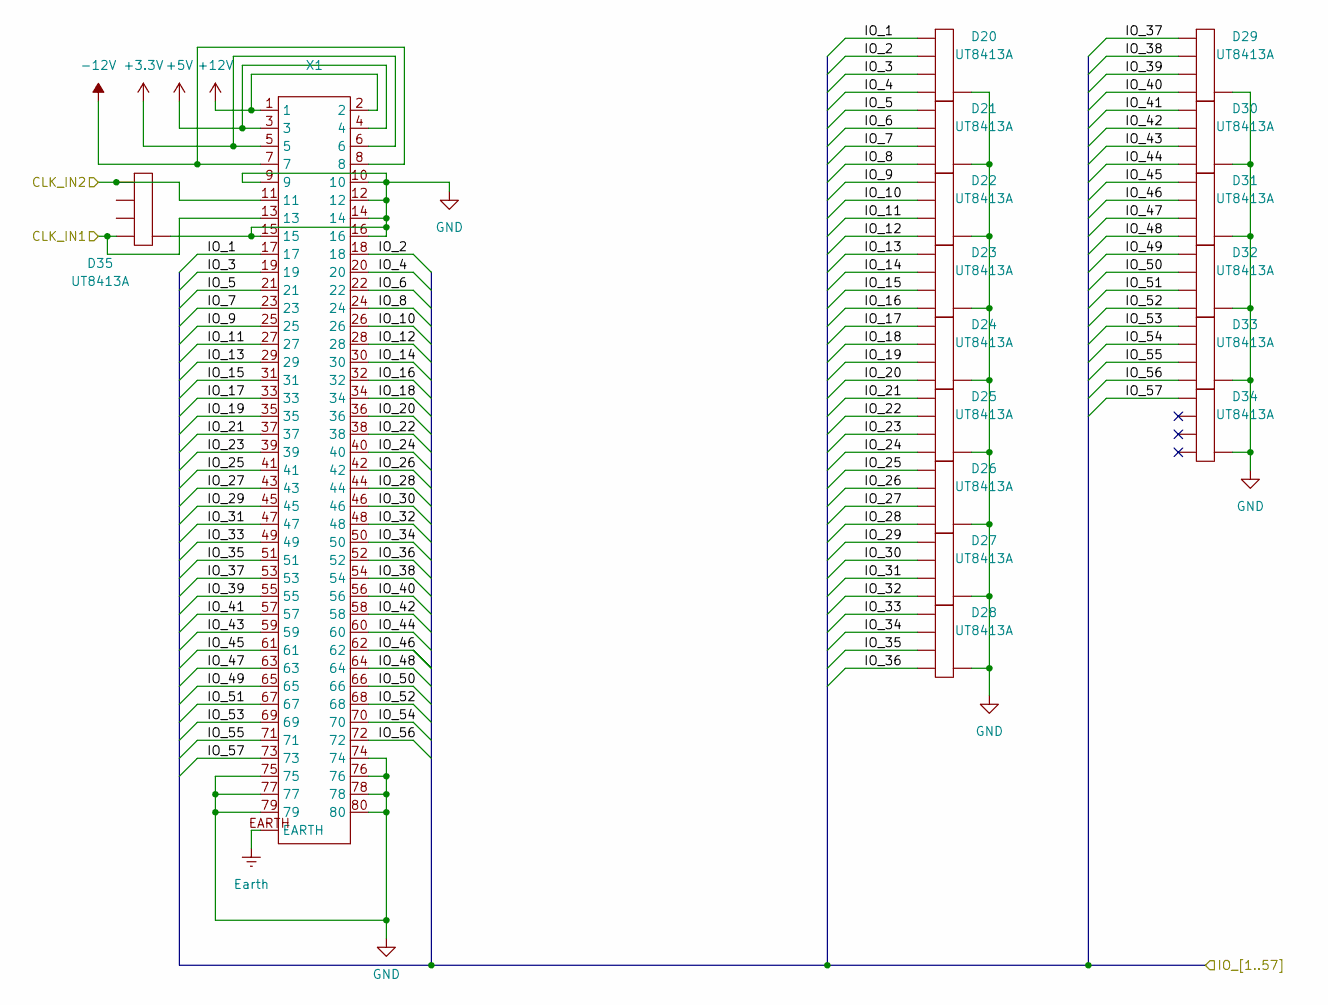
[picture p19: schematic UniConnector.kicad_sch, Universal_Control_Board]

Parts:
D20, D21, D22, D23, D24, D25, D26, D27, D28, D29, D30, D31, D32, D33, D34, D35: UT8413A; Diodes_UDFN-10_1.0x2.5mm_P0.5mm; Manufacturer_Part_Number UT8413A
X1: UniConnector

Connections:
+3.3V: X1.5, X1.6; also elsewhere on the board
+5V: X1.3, X1.4; also elsewhere on the board
+12V: X1.1, X1.2; also elsewhere on the board
-12V: X1.7, X1.8; also elsewhere on the board
/MCU/IO_1: D20.5, D20.6, X1.17; also elsewhere on the board
/MCU/IO_2: D20.4, D20.7, X1.18; also elsewhere on the board
/MCU/IO_3: D20.2, D20.9, X1.19; also elsewhere on the board
/MCU/IO_4: D20.1, D20.10, X1.20; also elsewhere on the board
/MCU/IO_5: D21.5, D21.6, X1.21; also elsewhere on the board
/MCU/IO_6: D21.4, D21.7, X1.22; also elsewhere on the board
/MCU/IO_7: D21.2, D21.9, X1.23; also elsewhere on the board
/MCU/IO_8: D21.1, D21.10, X1.24; also elsewhere on the board
/MCU/IO_9: D22.5, D22.6, X1.25; also elsewhere on the board
/MCU/IO_10: D22.4, D22.7, X1.26; also elsewhere on the board
/MCU/IO_11: D22.2, D22.9, X1.27; also elsewhere on the board
/MCU/IO_12: D22.1, D22.10, X1.28; also elsewhere on the board
/MCU/IO_13: D23.5, D23.6, X1.29; also elsewhere on the board
/MCU/IO_14: D23.4, D23.7, X1.30; also elsewhere on the board
/MCU/IO_15: D23.2, D23.9, X1.31; also elsewhere on the board
/MCU/IO_16: D23.1, D23.10, X1.32; also elsewhere on the board
/MCU/IO_17: D24.5, D24.6, X1.33; also elsewhere on the board
/MCU/IO_18: D24.4, D24.7, X1.34; also elsewhere on the board
/MCU/IO_19: D24.2, D24.9, X1.35; also elsewhere on the board
/MCU/IO_20: D24.1, D24.10, X1.36; also elsewhere on the board
/MCU/IO_21: D25.5, D25.6, X1.37; also elsewhere on the board
/MCU/IO_22: D25.4, D25.7, X1.38; also elsewhere on the board
/MCU/IO_23: D25.2, D25.9, X1.39; also elsewhere on the board
/MCU/IO_24: D25.1, D25.10, X1.40; also elsewhere on the board
/MCU/IO_25: D26.5, D26.6, X1.41; also elsewhere on the board
/MCU/IO_26: D26.4, D26.7, X1.42; also elsewhere on the board
/MCU/IO_27: D26.2, D26.9, X1.43; also elsewhere on the board
/MCU/IO_28: D26.1, D26.10, X1.44; also elsewhere on the board
/MCU/IO_29: D27.5, D27.6, X1.45; also elsewhere on the board
/MCU/IO_30: D27.4, D27.7, X1.46; also elsewhere on the board
/MCU/IO_31: D27.2, D27.9, X1.47; also elsewhere on the board
/MCU/IO_32: D27.1, D27.10, X1.48; also elsewhere on the board
/MCU/IO_33: D28.5, D28.6, X1.49; also elsewhere on the board
/MCU/IO_34: D28.4, D28.7, X1.50; also elsewhere on the board
/MCU/IO_35: D28.2, D28.9, X1.51; also elsewhere on the board
/MCU/IO_36: D28.1, D28.10, X1.52; also elsewhere on the board
/MCU/IO_37: D29.5, D29.6, X1.53; also elsewhere on the board
/MCU/IO_38: D29.4, D29.7, X1.54; also elsewhere on the board
/MCU/IO_39: D29.2, D29.9, X1.55; also elsewhere on the board
/MCU/IO_40: D29.1, D29.10, X1.56; also elsewhere on the board
/MCU/IO_41: D30.5, D30.6, X1.57; also elsewhere on the board
/MCU/IO_42: D30.4, D30.7, X1.58; also elsewhere on the board
/MCU/IO_43: D30.2, D30.9, X1.59; also elsewhere on the board
/MCU/IO_44: D30.1, D30.10, X1.60; also elsewhere on the board
/MCU/IO_45: D31.5, D31.6, X1.61; also elsewhere on the board
/MCU/IO_46: D31.4, D31.7, X1.62; also elsewhere on the board
/MCU/IO_47: D31.2, D31.9, X1.63; also elsewhere on the board
/MCU/IO_48: D31.1, D31.10, X1.64; also elsewhere on the board
/MCU/IO_49: D32.5, D32.6, X1.65; also elsewhere on the board
/MCU/IO_50: D32.4, D32.7, X1.66; also elsewhere on the board
/MCU/IO_51: D32.2, D32.9, X1.67; also elsewhere on the board
/MCU/IO_52: D32.1, D32.10, X1.68; also elsewhere on the board
/MCU/IO_53: D33.5, D33.6, X1.69; also elsewhere on the board
/MCU/IO_54: D33.4, D33.7, X1.70; also elsewhere on the board
/MCU/IO_55: D33.2, D33.9, X1.71; also elsewhere on the board
/MCU/IO_56: D33.1, D33.10, X1.72; also elsewhere on the board
/MCU/IO_57: D34.5, D34.6, X1.73; also elsewhere on the board
/UniConnector/CLK_IN1: D35.1, D35.10, X1.13; also elsewhere on the board
/UniConnector/CLK_IN2: D35.5, D35.6, X1.11; also elsewhere on the board
Earth: X1.EARTH; also elsewhere on the board
GND: D20.3, D20.8, D21.3, D21.8, D22.3, D22.8, D23.3, D23.8, D24.3, D24.8, D25.3, D25.8, D26.3, D26.8, D27.3, D27.8, D28.3, D28.8, D29.3, D29.8, D30.3, D30.8, D31.3, D31.8, D32.3, D32.8, D33.3, D33.8, D34.3, D34.8, D35.3, D35.8, X1.9, X1.10, X1.12, X1.14, X1.15, X1.16, X1.74, X1.75, X1.76, X1.77, X1.78, X1.79, X1.80; also elsewhere on the board
unnamed: D35.2, D35.9
unnamed: D35.4, D35.7

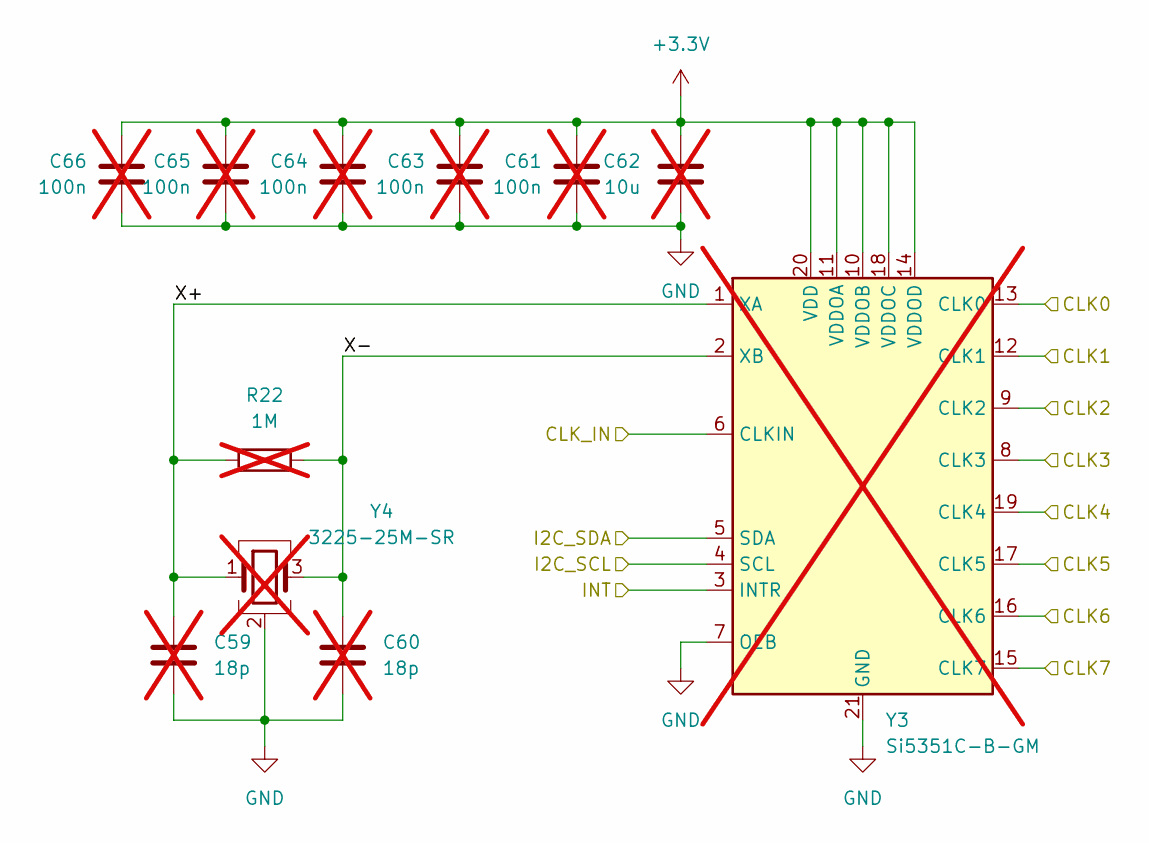
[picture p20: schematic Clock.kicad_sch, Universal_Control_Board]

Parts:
C59, C60: 18p; C_0402_1005Metric; not fitted
C61, C63, C64, C65, C66: 100n; C_0603_1608Metric; Manufacturer_Part_Number GRM188R71H104KA93D; not fitted
C62: 10u; C_1206_3216Metric; Manufacturer_Part_Number CL31B106KBHNNNE; not fitted
R22: 1M; R_0603_1608Metric; Manufacturer_Part_Number 0603SAF1004T5E; not fitted
Y3: Si5351C-B-GM; QFN-20-1EP_4x4mm_P0.5mm_EP2.5x2.5mm; Manufacturer_Part_Number Si5351C-B-GM; not fitted
Y4: 3225-25M-SR; Crystal_SMD_3225-4Pin_3.2x2.5mm; Manufacturer_Part_Number 3225-25M-SR; not fitted

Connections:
+3.3V: C61.2, C62.1, C63.2, C64.2, C65.2, C66.2, Y3.10 (VDDOB), Y3.11 (VDDOA), Y3.14 (VDDOD), Y3.18 (VDDOC), Y3.20 (VDD); also elsewhere on the board
/Clock/CLK0: Y3.13 (CLK0); also elsewhere on the board
/Clock/CLK1: Y3.12 (CLK1); also elsewhere on the board
/Clock/CLK2: Y3.9 (CLK2); also elsewhere on the board
/Clock/CLK3: Y3.8 (CLK3); also elsewhere on the board
/Clock/CLK4: Y3.19 (CLK4)
/Clock/CLK5: Y3.17 (CLK5)
/Clock/CLK6: Y3.16 (CLK6)
/Clock/CLK7: Y3.15 (CLK7)
/Clock/CLK_IN: Y3.6 (CLKIN); also elsewhere on the board
/Clock/INT: Y3.3 (INTR)
/Clock/X+: C59.1, R22.1, Y3.1 (XA), Y4.1
/Clock/X-: C60.1, R22.2, Y3.2 (XB), Y4.3
/MCU/SCL: Y3.4 (SCL); also elsewhere on the board
/MCU/SDA: Y3.5 (SDA); also elsewhere on the board
GND: C59.2, C60.2, C61.1, C62.2, C63.1, C64.1, C65.1, C66.1, Y3.7 (OEB), Y3.21 (GND), Y4.2 (G), Y4.4 (G); also elsewhere on the board

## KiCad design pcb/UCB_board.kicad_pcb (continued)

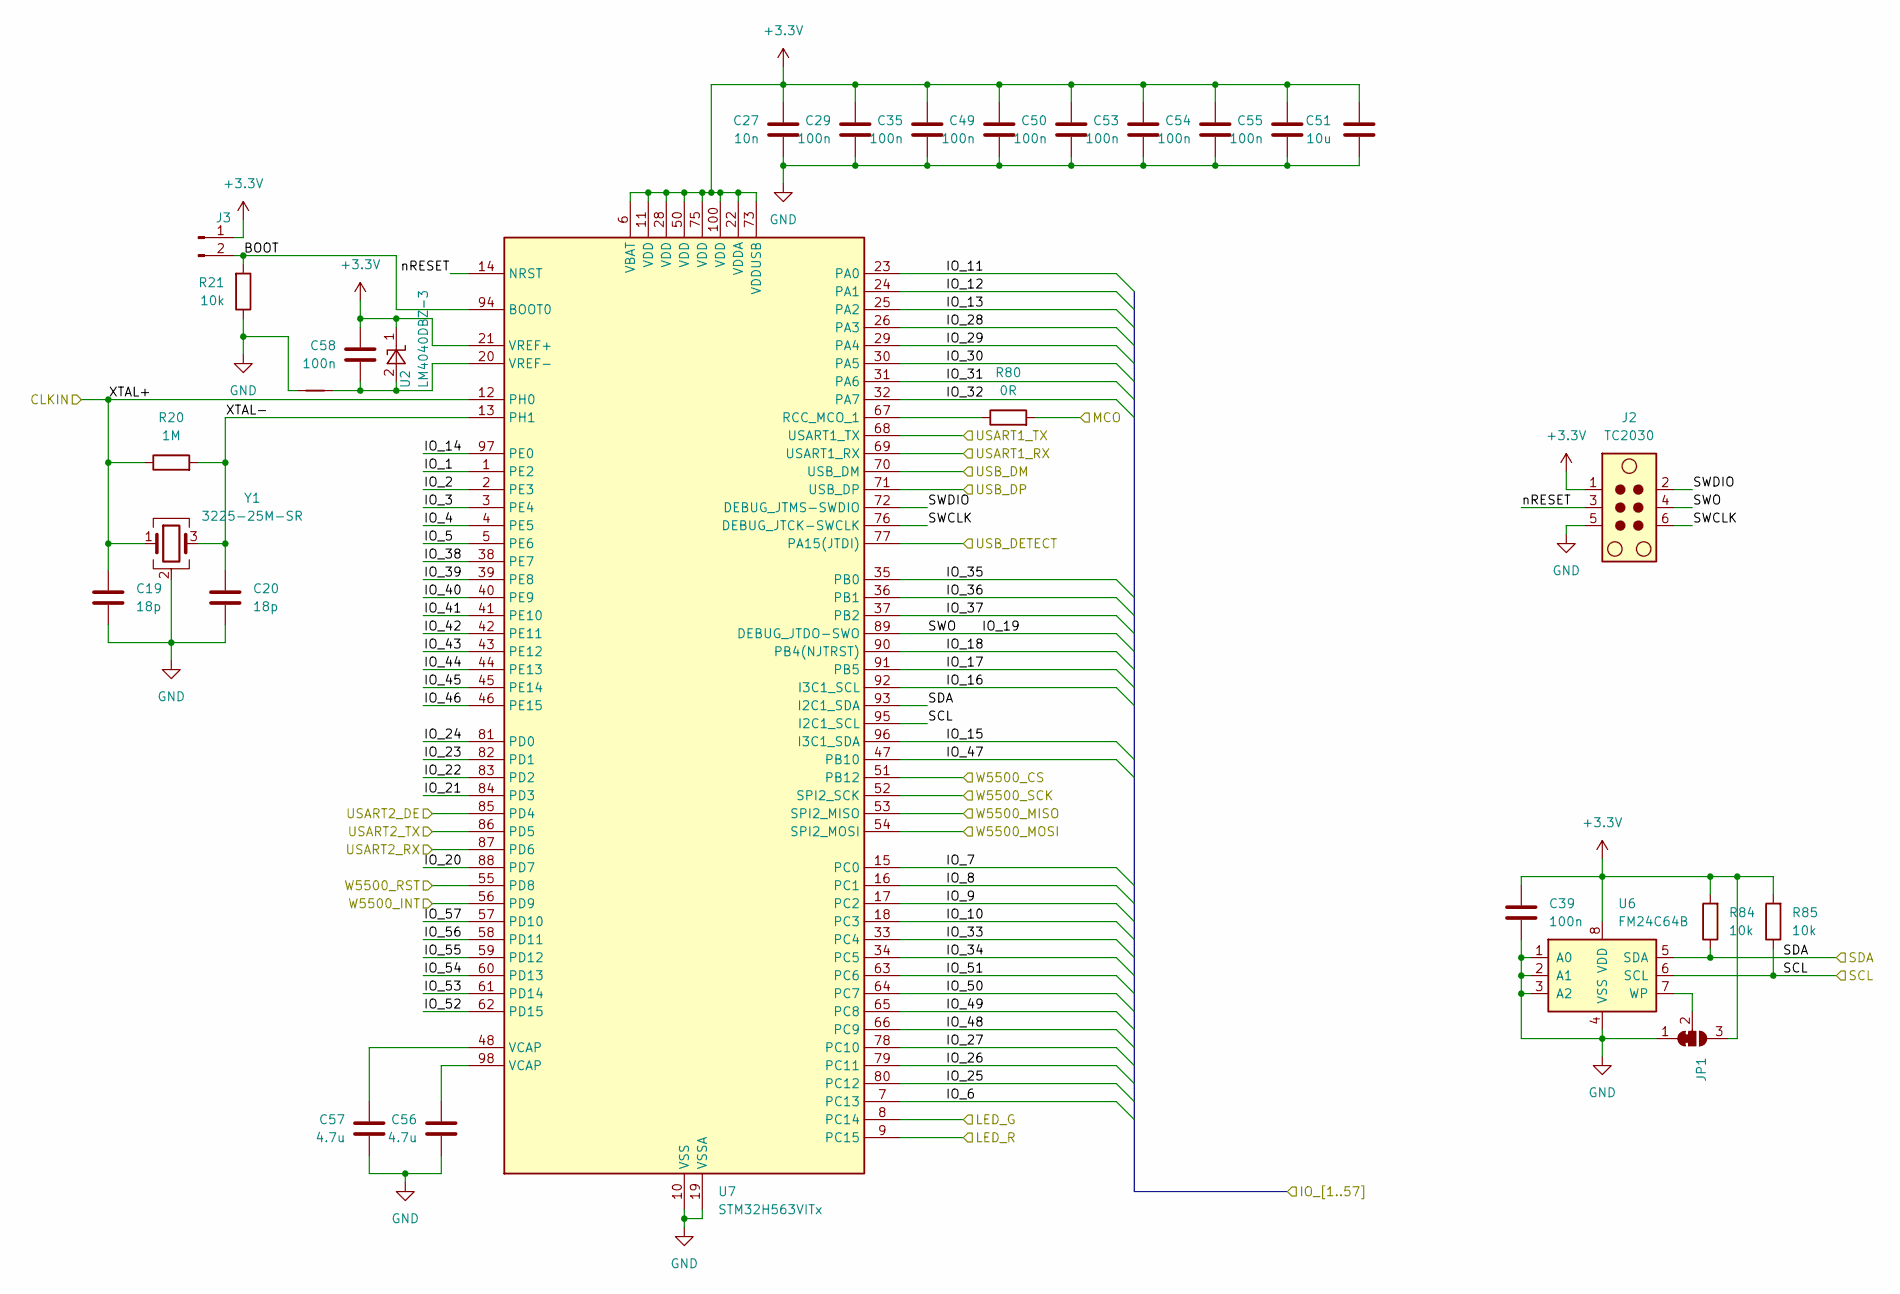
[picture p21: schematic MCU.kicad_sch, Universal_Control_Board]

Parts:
C19, C20: 18p; C_0402_1005Metric_Pad0.74x0.62mm_HandSolder
C27: 10n; C_0603_1608Metric; Manufacturer_Part_Number GRM1885C1H103JA01J
C29, C35, C39, C49, C50, C53, C54, C55, C58: 100n; C_0603_1608Metric; Manufacturer_Part_Number GRM188R71H104KA93D
C51: 10u; C_1206_3216Metric; Manufacturer_Part_Number CL31B106KBHNNNE
C56, C57: 4.7u; C_0603_1608Metric; Manufacturer_Part_Number 0603X475K100CT
J2: TC2030; Tag-Connect_TC2030-IDC-NL_2x03_P1.27mm_Vertical
J3: Conn_01x02_Pin; PinHeader_1x02_P2.00mm_Vertical
JP1: SolderJumper_3_Bridged12; SolderJumper-3_P1.3mm_Bridged12_Pad1.0x1.5mm
NT1: NetTie_2; NetTie-2_SMD_Pad0.5mm
R20: 1M; R_0603_1608Metric; Manufacturer_Part_Number 0603SAF1004T5E
R21, R84, R85: 10k; R_0603_1608Metric; Manufacturer_Part_Number CRCW060310K0FKTABC
R80: 0R; R_0402_1005Metric; Manufacturer_Part_Number CRCW04020000Z0TDBC
U2: LM4040DBZ-3; SOT-23_Handsoldering; Manufacturer_Part_Number LM4040DBZ-3
U6: FM24C64B; SOIC-8_3.9x4.9mm_P1.27mm; Manufacturer_Part_Number FM24C64B
U7: STM32H563VITx; LQFP-100_14x14mm_P0.5mm; Manufacturer_Part_Number STM32H563VIT6
Y1: 3225-25M-SR; Crystal_SMD_3225-4Pin_3.2x2.5mm

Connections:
+3.3V: C27.2, C29.2, C35.2, C39.1, C49.2, C50.2, C51.1, C53.2, C54.2, C55.2, C58.2, J2.1, J3.1, JP1.3 (B), R84.2, R85.2, U2.1 (K), U6.8 (VDD), U7.6 (VBAT), U7.11 (VDD), U7.21 (VREF+), U7.22 (VDDA), U7.28 (VDD), U7.50 (VDD), U7.73 (VDDUSB), U7.75 (VDD), U7.100 (VDD); also elsewhere on the board
/ConnectorDIN41612/DE: U7.85 (PD4); also elsewhere on the board
/ConnectorDIN41612/RxD: U7.87 (PD6); also elsewhere on the board
/ConnectorDIN41612/TxD: U7.86 (PD5); also elsewhere on the board
/ConnectorDIN41612/USART+: U7.68 (USART1_TX); also elsewhere on the board
/ConnectorDIN41612/USART-: U7.69 (USART1_RX); also elsewhere on the board
/ConnectorDIN41612/USB_D+: U7.71 (USB_DP); also elsewhere on the board
/ConnectorDIN41612/USB_D-: U7.70 (USB_DM); also elsewhere on the board
/ConnectorDIN41612/USB_DET: U7.77 (PA15(JTDI)); also elsewhere on the board
/EthernetPHY/CS: U7.51 (PB12); also elsewhere on the board
/EthernetPHY/INT: U7.56 (PD9); also elsewhere on the board
/EthernetPHY/MISO: U7.53 (SPI2_MISO); also elsewhere on the board
/EthernetPHY/MOSI: U7.54 (SPI2_MOSI); also elsewhere on the board
/EthernetPHY/RST: U7.55 (PD8); also elsewhere on the board
/EthernetPHY/SCK: U7.52 (SPI2_SCK); also elsewhere on the board
/EthernetPHY/XO+: R80.2; also elsewhere on the board
/MCU/BOOT: J3.2, R21.2, U7.94 (BOOT0)
/MCU/IO_1: U7.1 (PE2); also elsewhere on the board
/MCU/IO_2: U7.2 (PE3); also elsewhere on the board
/MCU/IO_3: U7.3 (PE4); also elsewhere on the board
/MCU/IO_4: U7.4 (PE5); also elsewhere on the board
/MCU/IO_5: U7.5 (PE6); also elsewhere on the board
/MCU/IO_6: U7.7 (PC13); also elsewhere on the board
/MCU/IO_7: U7.15 (PC0); also elsewhere on the board
/MCU/IO_8: U7.16 (PC1); also elsewhere on the board
/MCU/IO_9: U7.17 (PC2); also elsewhere on the board
/MCU/IO_10: U7.18 (PC3); also elsewhere on the board
/MCU/IO_11: U7.23 (PA0); also elsewhere on the board
/MCU/IO_12: U7.24 (PA1); also elsewhere on the board
/MCU/IO_13: U7.25 (PA2); also elsewhere on the board
/MCU/IO_14: U7.97 (PE0); also elsewhere on the board
/MCU/IO_15: U7.96 (I3C1_SDA); also elsewhere on the board
/MCU/IO_16: U7.92 (I3C1_SCL); also elsewhere on the board
/MCU/IO_17: U7.91 (PB5); also elsewhere on the board
/MCU/IO_18: U7.90 (PB4(NJTRST)); also elsewhere on the board
/MCU/IO_19: J2.4, U7.89 (DEBUG_JTDO-SWO); also elsewhere on the board
/MCU/IO_20: U7.88 (PD7); also elsewhere on the board
/MCU/IO_21: U7.84 (PD3); also elsewhere on the board
/MCU/IO_22: U7.83 (PD2); also elsewhere on the board
/MCU/IO_23: U7.82 (PD1); also elsewhere on the board
/MCU/IO_24: U7.81 (PD0); also elsewhere on the board
/MCU/IO_25: U7.80 (PC12); also elsewhere on the board
/MCU/IO_26: U7.79 (PC11); also elsewhere on the board
/MCU/IO_27: U7.78 (PC10); also elsewhere on the board
/MCU/IO_28: U7.26 (PA3); also elsewhere on the board
/MCU/IO_29: U7.29 (PA4); also elsewhere on the board
/MCU/IO_30: U7.30 (PA5); also elsewhere on the board
/MCU/IO_31: U7.31 (PA6); also elsewhere on the board
/MCU/IO_32: U7.32 (PA7); also elsewhere on the board
/MCU/IO_33: U7.33 (PC4); also elsewhere on the board
/MCU/IO_34: U7.34 (PC5); also elsewhere on the board
/MCU/IO_35: U7.35 (PB0); also elsewhere on the board
/MCU/IO_36: U7.36 (PB1); also elsewhere on the board
/MCU/IO_37: U7.37 (PB2); also elsewhere on the board
/MCU/IO_38: U7.38 (PE7); also elsewhere on the board
/MCU/IO_39: U7.39 (PE8); also elsewhere on the board
/MCU/IO_40: U7.40 (PE9); also elsewhere on the board
/MCU/IO_41: U7.41 (PE10); also elsewhere on the board
/MCU/IO_42: U7.42 (PE11); also elsewhere on the board
/MCU/IO_43: U7.43 (PE12); also elsewhere on the board
/MCU/IO_44: U7.44 (PE13); also elsewhere on the board
/MCU/IO_45: U7.45 (PE14); also elsewhere on the board
/MCU/IO_46: U7.46 (PE15); also elsewhere on the board
/MCU/IO_47: U7.47 (PB10); also elsewhere on the board
/MCU/IO_48: U7.66 (PC9); also elsewhere on the board
/MCU/IO_49: U7.65 (PC8); also elsewhere on the board
/MCU/IO_50: U7.64 (PC7); also elsewhere on the board
/MCU/IO_51: U7.63 (PC6); also elsewhere on the board
/MCU/IO_52: U7.62 (PD15); also elsewhere on the board
/MCU/IO_53: U7.61 (PD14); also elsewhere on the board
/MCU/IO_54: U7.60 (PD13); also elsewhere on the board
/MCU/IO_55: U7.59 (PD12); also elsewhere on the board
/MCU/IO_56: U7.58 (PD11); also elsewhere on the board
/MCU/IO_57: U7.57 (PD10); also elsewhere on the board
/MCU/LED_G: U7.8 (PC14); also elsewhere on the board
/MCU/LED_R: U7.9 (PC15); also elsewhere on the board
/MCU/SCL: R85.1, U6.6 (SCL), U7.95 (I2C1_SCL); also elsewhere on the board
/MCU/SDA: R84.1, U6.5 (SDA), U7.93 (I2C1_SDA); also elsewhere on the board
/MCU/SWCLK: J2.6, U7.76 (DEBUG_JTCK-SWCLK)
/MCU/SWDIO: J2.2, U7.72 (DEBUG_JTMS-SWDIO)
/MCU/XTAL+: C19.1, R20.1, U7.12 (PH0), Y1.1; also elsewhere on the board
/MCU/XTAL-: C20.1, R20.2, U7.13 (PH1), Y1.3
/MCU/nRESET: J2.3, U7.14 (NRST)
GND: C19.2, C20.2, C27.1, C29.1, C35.1, C39.2, C49.1, C50.1, C51.2, C53.1, C54.1, C55.1, C56.1, C57.1, J2.5, JP1.1 (A), NT1.1, R21.1, U6.1 (A0), U6.2 (A1), U6.3 (A2), U6.4 (VSS), U7.10 (VSS), U7.19 (VSSA), U7.27 (VSS), U7.49 (VSS), U7.74 (VSS), U7.99 (VSS), Y1.2 (G), Y1.4 (G); also elsewhere on the board
unnamed: C56.2, U7.98 (VCAP)
unnamed: C57.2, U7.48 (VCAP)
unnamed: JP1.2 (C), U6.7 (WP)
unnamed: C58.1, NT1.2, U2.2 (A), U7.20 (VREF-)
unnamed: R80.1, U7.67 (RCC_MCO_1)

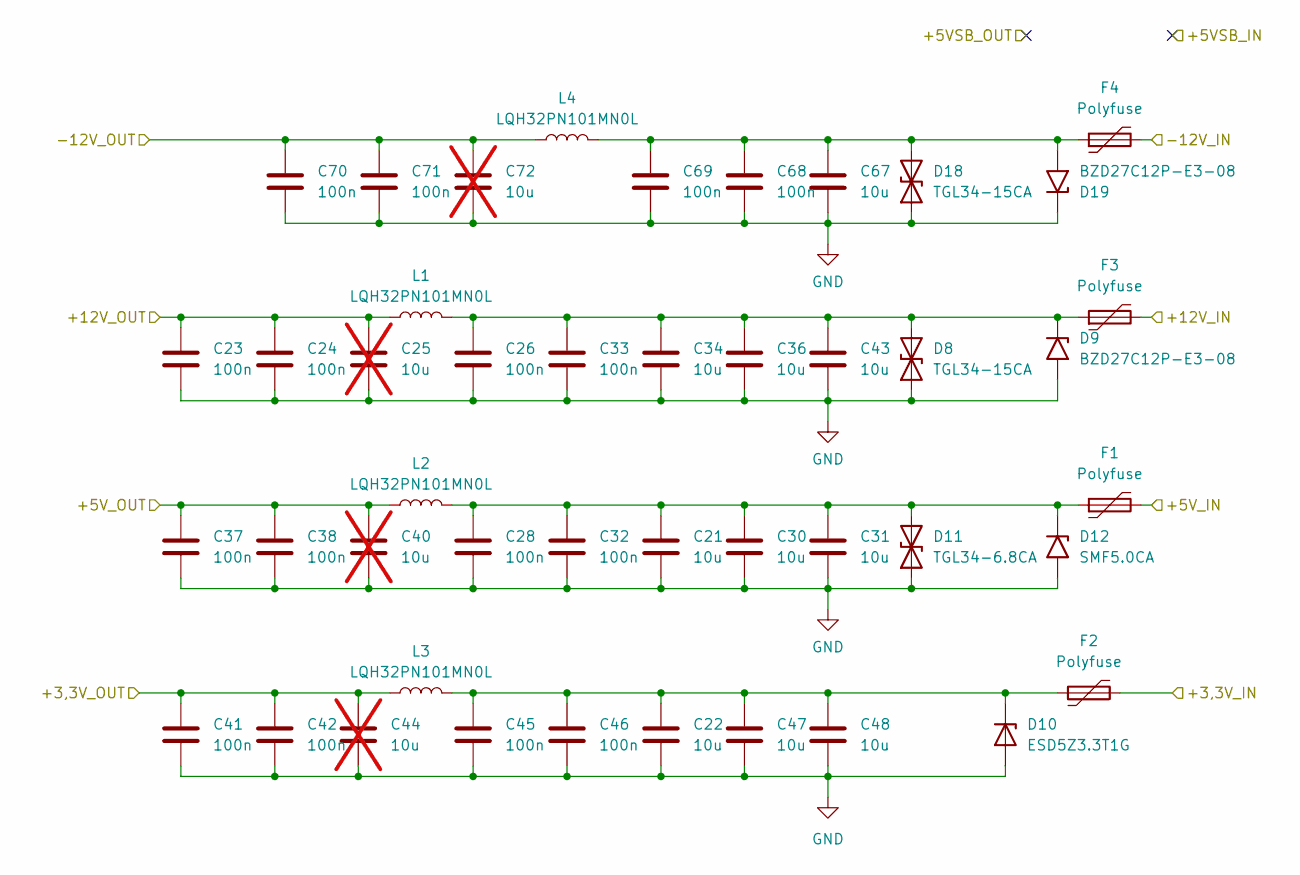
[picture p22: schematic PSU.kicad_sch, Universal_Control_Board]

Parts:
C21, C22, C30, C31, C34, C36, C43, C47, C48, C67: 10u; C_1206_3216Metric; Manufacturer_Part_Number CL31B106KBHNNNE
C23, C24, C26, C28, C32, C33, C37, C38, C41, C42, C45, C46, C68, C69, C70, C71: 100n; C_0603_1608Metric; Manufacturer_Part_Number GRM188R71H104KA93D
C25, C40, C44, C72: 10u; C_1206_3216Metric_Pad1.33x1.80mm_HandSolder; not fitted
D8, D18: TGL34-15CA; D_MiniMELF; Manufacturer_Part_Number TGL34-15CA
D9, D19: BZD27C12P-E3-08; D_SMF; Manufacturer_Part_Number BZD27C12P-E3-08
D10: ESD5Z3.3T1G; D_SOD-523; Manufacturer_Part_Number ESD5Z3.3T1G
D11: TGL34-6.8CA; D_MiniMELF; Manufacturer_Part_Number TGL34-6.8CA
D12: SMF5.0CA; D_SMF; Manufacturer_Part_Number SMF5.0CA
F1, F2, F3, F4: Polyfuse; Fuse_1206_3216Metric_Pad1.42x1.75mm_HandSolder; Manufacturer_Part_Number SN020-30
L1, L2, L3, L4: LQH32PN101MN0L; L_1210_3225Metric; Manufacturer_Part_Number LQH32PN101MN0L

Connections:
+3.3V: C41.1, C42.1, C44.1, L3.1; also elsewhere on the board
+5V: C37.1, C38.1, C40.1, L2.1; also elsewhere on the board
+12V: C23.1, C24.1, C25.1, L1.1; also elsewhere on the board
-12V: C70.1, C71.1, C72.1, L4.1; also elsewhere on the board
/ConnectorDIN41612/PSU/+3,3V_IN: F2.2; also elsewhere on the board
/ConnectorDIN41612/PSU/+5V_IN: F1.2; also elsewhere on the board
/ConnectorDIN41612/PSU/+12V_IN: F3.2; also elsewhere on the board
/ConnectorDIN41612/PSU/-12V_IN: F4.2; also elsewhere on the board
GND: C21.2, C22.2, C23.2, C24.2, C25.2, C26.2, C28.2, C30.2, C31.2, C32.2, C33.2, C34.2, C36.2, C37.2, C38.2, C40.2, C41.2, C42.2, C43.2, C44.2, C45.2, C46.2, C47.2, C48.2, C67.2, C68.2, C69.2, C70.2, C71.2, C72.2, D8.1 (A1), D9.2 (A2), D10.2 (A), D11.1 (A1), D12.2 (A2), D18.1 (A1), D19.1 (A1); also elsewhere on the board
unnamed: C26.1, C33.1, C34.1, C36.1, C43.1, D8.2 (A2), D9.1 (A1), F3.1, L1.2
unnamed: C22.1, C45.1, C46.1, C47.1, C48.1, D10.1 (K), F2.1, L3.2
unnamed: C21.1, C28.1, C30.1, C31.1, C32.1, D11.2 (A2), D12.1 (A1), F1.1, L2.2
unnamed: C67.1, C68.1, C69.1, D18.2 (A2), D19.2 (A2), F4.1, L4.2

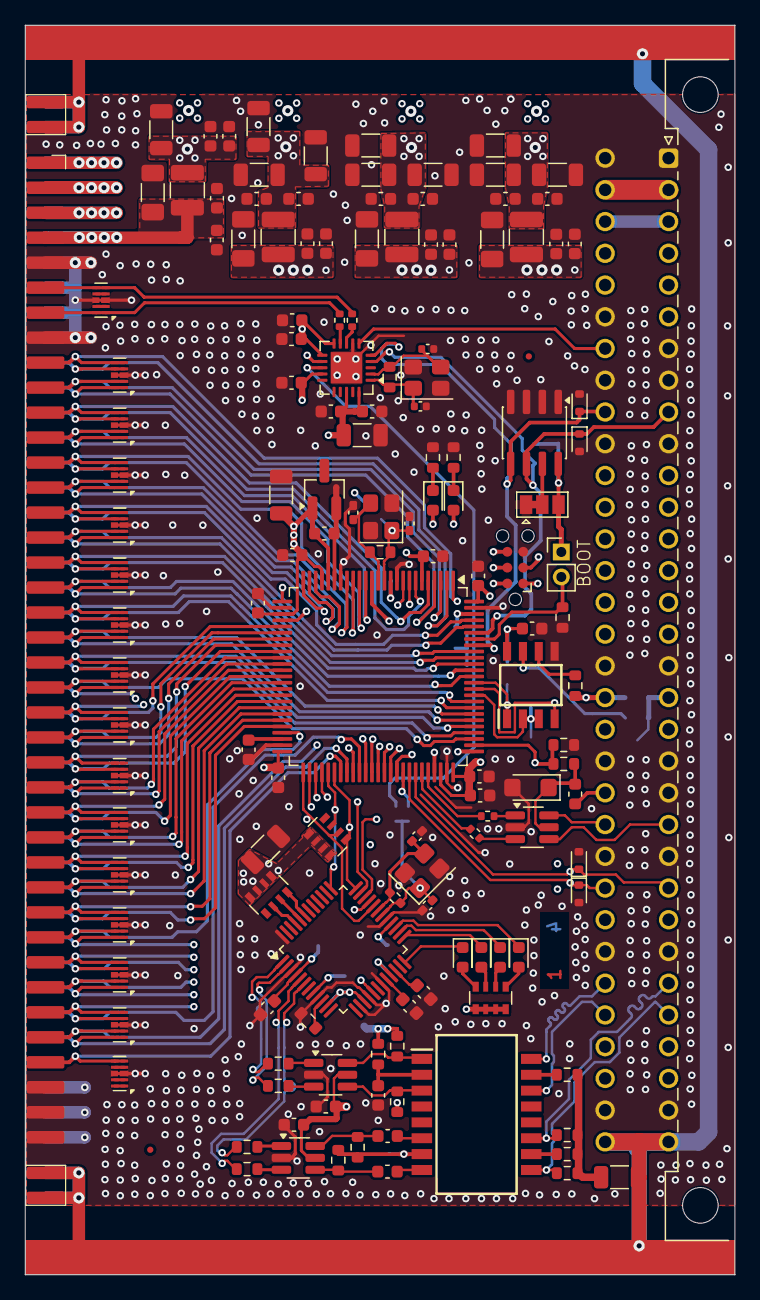
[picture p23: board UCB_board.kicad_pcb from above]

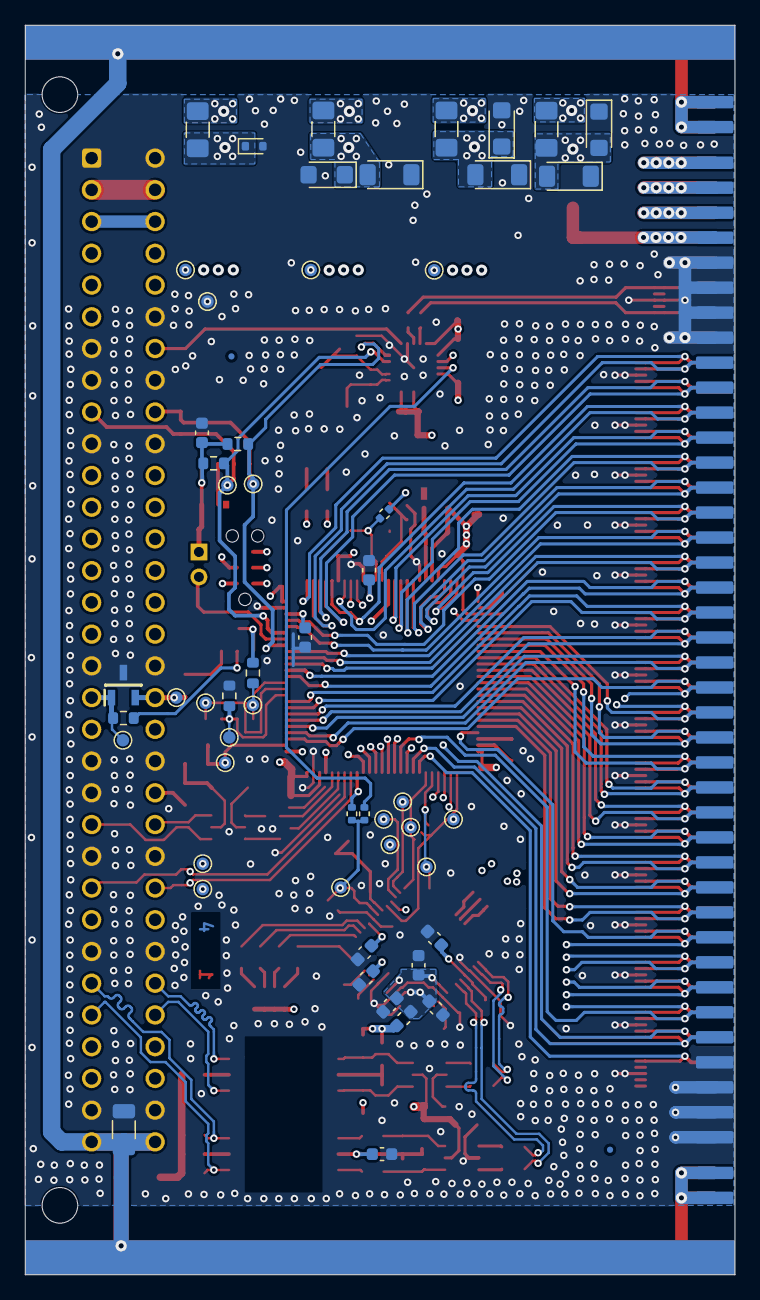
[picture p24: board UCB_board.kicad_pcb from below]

Board: 4 copper layers, 56.8 x 100.0 mm, 201 parts (55 on the bottom side), 163 nets.

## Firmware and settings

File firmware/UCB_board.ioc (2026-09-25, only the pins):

Mcu.UserName=STM32H563VITx
PA10.Signal=USART1_RX
PA11.Signal=USB_DM
PA12.Signal=USB_DP
PA13(JTMS/SWDIO).Signal=DEBUG_JTMS-SWDIO
PA14(JTCK/SWCLK).Signal=DEBUG_JTCK-SWCLK
PA15(JTDI).GPIO_Label=USB_DETECT
PA15(JTDI).Signal=GPIO_Input
PA8.Signal=RCC_MCO_1
PA9.Signal=USART1_TX
PB12.GPIO_Label=W5500_CS
PB12.Signal=GPIO_Output
PB13.GPIO_Label=W5500_SCK
PB13.Signal=SPI2_SCK
PB14.GPIO_Label=W5500_MISO
PB14.Signal=SPI2_MISO
PB15.GPIO_Label=W5500_MOSI
PB15.Signal=SPI2_MOSI
PB7.Signal=I2C1_SDA
PB8.Signal=I2C1_SCL
PC14-OSC32_IN(OSC32_IN).Signal=GPIO_Output
PC15-OSC32_OUT(OSC32_OUT).Signal=GPIO_Output
PD4.Signal=USART2_DE
PD5.Signal=USART2_TX
PD6.Signal=USART2_RX
PD8.GPIO_Label=W5500_RST
PD8.Signal=GPIO_Output
PD9.GPIO_Label=W5500_INT
PD9.Signal=GPIO_Input
PH0-OSC_IN(PH0).Signal=RCC_OSC_IN
PH1-OSC_OUT(PH1).Signal=RCC_OSC_OUT

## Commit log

2026-03-27 Project files upload
    [ConnDIN41612.kicad_sch, EthernetPHY.kicad_sch, MCU.kicad_sch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]
2026-03-30 New power design
    [ConnDIN41612.kicad_sch, PSU.kicad_sch, UCB_board.kicad_pcb]
2026-03-31 Add connections and new footprints
    [UCB_board.kicad_pcb]
2026-04-06 Add UniConnector for io expansion (2.0mm pinheader)
    [ConnDIN41612.kicad_sch, MCU.kicad_sch, UCB_board.kicad_pcb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]
2026-04-09 Add junction and bus entries to UniConnector schematic
    [MCU.kicad_sch, UCB_board.kicad_pcb, UniConnector.kicad_sch]
2026-04-13 UniConnector new traces
    [MCU.kicad_sch, UCB_board.kicad_pcb, UCB_board.kicad_sch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]
2026-04-14 Added SI5351C
    [Clock.kicad_sch, EthernetPHY.kicad_sch, MCU.kicad_sch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]
2026-04-14 Clock rounting
    [Clock.kicad_sch, UCB_board.kicad_pcb, UCB_board.kicad_sch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]
2026-04-15 New routing
    [PSU.kicad_sch, UCB_board.kicad_pcb, UCB_board.kicad_sch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]
2026-04-15 More routing
    [UCB_board.kicad_pcb, UniConnector.kicad_sch]
2026-04-16 More routing ...
    [MCU.kicad_sch, UCB_board.kicad_pcb]
2026-04-17 Added ESD protection to UniConnector, more routing and polishing
    [ConnDIN41612.kicad_sch, UniConnector.kicad_sch]
2026-04-19 Added vias and cleaned pcb. Board finished
    [UCB_board.kicad_sch]
2026-04-19 Prepared for production
    [UCB_board-B_Cu.gbl, UCB_board-B_Mask.gbs, UCB_board-B_Paste.gbp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]
2026-04-21 Add ferrite beads; update MCU pinout
    Schematic and PCB updates: add FerriteBead_Small symbol two instances (FB1, FB2) with matching 0603 inductor footprints on the board. Firmware (.ioc) changes: removed I3C config, added TIM2/TIM5/USART mappings, configured timer channels for input capture, and relabeled pins for the W5500 SPI signals (CS/SCK/MISO/MOSI) plus reset/INT. PCB layout tweaks: new inductor footprint, pad/net reassignments, silkscreen/label coordinate adjustments and various footprint placement/orientation fixes. Also updated board media images and regenerated production files/gerbers.
    [ConnDIN41612.kicad_sch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]
2026-05-10 Crystal footprint changed, routing and eth trafo to correct
    [Clock.kicad_sch, EthernetPHY.kicad_sch, MCU.kicad_sch]
2026-05-11 Corected mistakes found on RDE_board
    [ConnDIN41612.kicad_sch, EthernetPHY.kicad_sch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]
2026-07-14 PartNumber update
    [Clock.kicad_sch, ConnDIN41612.kicad_sch, EthernetPHY.kicad_sch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]
2026-08-27 Unify component values/footprints per checklist; add via-in-pad DRC rule; regenerate production outputs
    [Clock.kicad_sch, ConnDIN41612.kicad_sch, EthernetPHY.kicad_sch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]
2026-09-25 Apply review checklist fixes, add fiducials, regenerate production outputs
    - W5500 clock from MCU MCO1 by default (R80 fitted, R23 DNP)
    - Firmware .ioc: I2C1_SCL moved to PB8 to match schematic
    - 2 fiducials per side (hand assembly), zones refilled
    - Restore DRC exclusions dropped from .kicad_pro on last save (59, unchanged set)
    - README: status updated (ready for prototype order), renders and production links
    - .gitignore: drop leftover RDE_board ibom.config.ini entry
    - Regenerate BOM, PDFs, gerber zip, interactive BOM and 3D renders
    [Clock.kicad_sch, MCU.kicad_sch, UCB_board.csv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]
2026-09-28 Fix BOM data: 0603 LED part number (D1/D2/D4/D6/D13/D14), BOM field cleanup
    [ConnDIN41612.kicad_sch, EthernetPHY.kicad_sch, MCU.kicad_sch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]
2026-09-28 Regenerate production outputs and gerber zip after BOM field fixes
    [UCB_board.csv]
